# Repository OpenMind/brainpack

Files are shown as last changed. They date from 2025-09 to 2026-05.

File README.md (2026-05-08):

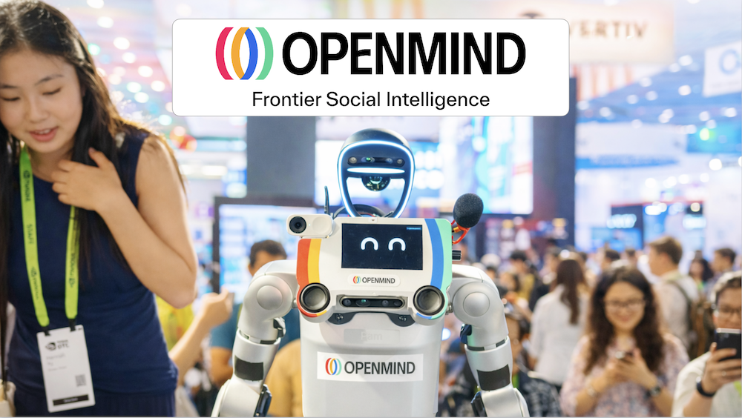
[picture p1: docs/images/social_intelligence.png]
OpenMind Scoial Intelligence


# BrainPack for Unitree G1, Unitree Go2, and LimX Tron 1

## Introduction

The **BrainPack** provides an easy to use, modular compute and development platform for robotics, integrated with the Unitree G1, Unitree Go2, and LimX Tron 1 (and other robots, coming soon). 

Included in the design are sensors and outputs that allow your robot to understand and react to its environment and interact with humans. The BrainPack with [Nvidia Thor](https://developer.nvidia.com/blog/introducing-nvidia-jetson-thor-the-ultimate-platform-for-physical-ai/) can connect to OpenMind cloud endpoints for voice, spatial navigation, emotion generation, teleops, and other robot functionality. 

The purpose of the BrainPack is to empower rapid iteration and experimentation. It enables developers to explore vertical-specific solutions quickly, re-configuring the system efficiently to meet evolving research or customer needs.

## Cross-Platform - It's Wooftacular!

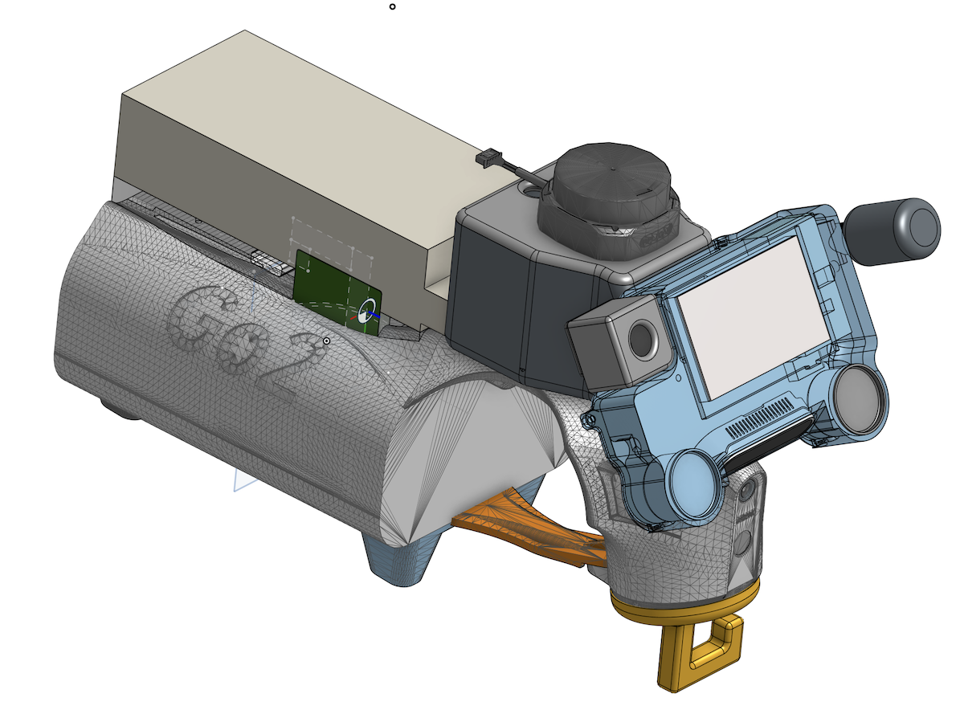
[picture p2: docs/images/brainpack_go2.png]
BrainPack OverView


## The Challenges in Robotics Development and Deployment

Currently, many robotics platforms are limited to academic research, single industrial problems, or for use as toys. When organizations attempt to deploy these robots into more complex and more realistic environments, significant limitations quickly become apparent.

### Hardware Limitations 

Common pain points include weak loudspeakers, lack of USB ports for additional sensors, lack of a touchscreen, lack of directional microphones, and outdated secondary computing modules. This means that even when purchasing a sophisticated robot such as Unitree G1, to conduct basic experiments and product development substantial time and effort must be spent on specialized cabling, 3D-printed parts, and add-on sensors.

### Fragmentation and Scalability

The robotics landscape is massive and highly fragmented. With over 400 active companies developing diverse robotic platforms and form factors, one impediment is the lack of hardware standards for integrating or swapping key components — whether that involves sensors, computing power, or power distribution. Imagine if your desktop PC were composed entirely of custom parts and you could not assemble the computer from standardized parts to fit your unique needs.

This forces developers into a difficult cycle: when a solution is built, it cannot be easily deployed across different robot brands and physical forms. This inefficiency means development efforts are tied to single-brand and single form factors. The BrainPack provides a standardized interface, establishing a common layer of capability that allows software and intelligence to run across multiple robot hardware platforms.

### Data Security and Privacy

For real world use of robots, it is important that humans feel comfortable in their presence, and this suggests physical privacy switches on cameras and microphones, as are standard for consumer webcams for example. The BrainPack allows cameras and microphones to be physically unplugged, or replaced with models that have privacy switches. Another feature commonly missing from most robots are indicator lights showing when cameras and microphones are active. 

### Our Solution: The BrainPack

We developed the BrainPack to address these blocks. This modular system provides deployment flexibility by providing one architecture that makes it easy to integrate, adapt, and explore diverse use cases. 

## Features

- **Designed for OM1** - Optimized for running OM1.
- **Human in the Loop** - Teleops - control your robot remotely or request help from another human whenever you need (via portal.openmind.com).
- **Developer Friendly** - Modular design with multiple connections and ports for easy hardware integration.

## Documentation

- [Bill of Materials](./docs/Materials.md)
- [CAD Files](./CAD/)
- [Assembly Instructions](./docs/Assembly.md)

## Repository Structure

```
PRISM/
├── README.md
├── docs/
│   ├── Materials.md       # Bill of Materials
│   └── Assembly.md        # Assembly Instructions
├── CAD/
    └──                    # STL files for 3D printing
```

## NonCommercial Use License

The contents of this repository — including CAD models, STL files, technical drawings, bill of materials, and assembly instructions for the OpenMind BrainPack — are released by OpenMind, Inc. under the Creative Commons Attribution-NonCommercial 4.0 International License (CC BY-NC 4.0): https://creativecommons.org/licenses/by-nc/4.0/

You are free to download, study, modify, fabricate for personal use, and share these materials for non-commercial purposes — including personal, educational, and academic-research use — provided you give appropriate credit to OpenMind, Inc., link to the license, and indicate any changes you have made.

Any commercial use is expressly reserved and requires a separate written license from OpenMind, Inc. "Commercial use" includes, without limitation: manufacturing the design (or any derivative of it) for sale; incorporating the design into a product, service, or system offered for sale or used commercially; using the design in connection with paid services; and distributing the design as part of any commercial offering.

No trademark rights in "OpenMind" or "BrainPack" any associated marks are granted by this license. No patent rights are granted, whether express or implied. OpenMind, Inc. retains all rights not expressly granted herein.

For commercial licensing inquiries, please contact hello@openmind.com.

---

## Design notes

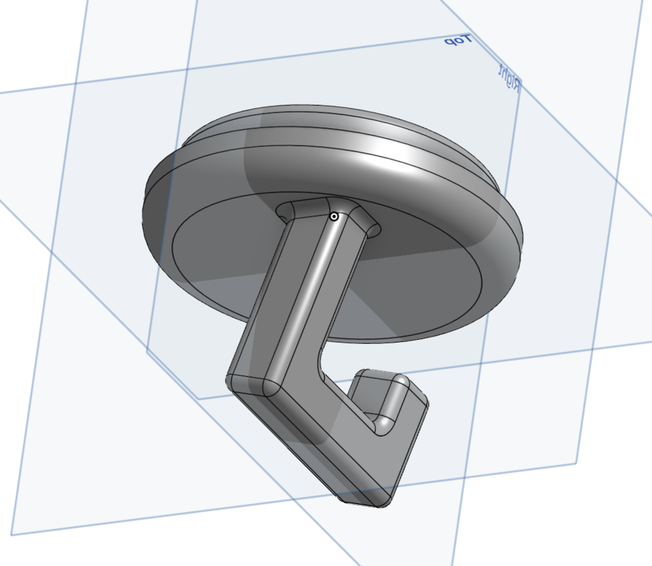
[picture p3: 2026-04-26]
docs/images/go2_mounth_hook.png

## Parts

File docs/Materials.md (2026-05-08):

<!-- TOC start (generated with https://github.com/derlin/bitdowntoc) -->
- [1. Safety](#safety)
   * [1.1 DANGER: Power Budget and Thermal Limits](#danger-power-budget-and-thermal-limits)
   * [1.2 DANGER: Robot Stability](#danger-robot-stability)
- [2. Materials](#materials)
   * [2.1 Display Unit ("Face")](#display-unit-face)
   * [2.2 Face and Sensor Carrier ("Head"); LiDAR](#face-mounting)
      + [2.2.1 Unitree G1](#unitree-g1)
      + [2.2.2 Unitree Go2 and LimX Tron 1](#unitree-go2-and-limx-tron-1)
   * [2.3 Thor Cradles](#thor-cradles)
      + [LimX Tron 1](#limx-tron-1)
      + [Unitree G1](#unitree-g1-1)
      + [Unitree Go2](#unitree-go2)
- [3. Cables and Power](#cables-and-power)
   * [3.1 Thor Power Harness](#thor-power-harness)
   * [3.2 Power Electronics](#power-electronics)
      + [LimX Tron 1 Power Cable](#limx-tron-1-power-cable)
      + [Unitree G1 Power Cable](#unitree-g1-power-cable)
      + [Unitree Go2 Power Cable](#unitree-go2-power-cable)
   * [3.3 Power Budget](#power-budget)
      + [Powered USB Hubs](#powered-usb-hubs)
      + [Example Power Calculation for Entire System](#power-budget-total)

<!-- TOC -->
# BrainPack Materials

> NOTE: Refer to the Bill of Materials with approximate build cost [here](https://docs.google.com/spreadsheets/d/1YjTzyw0XH3A2SuCKs4Oi_q3m2KCcntqwOuZ239gBQtQ).
> Prices can vary based on supplier, region, availability, and where generic items are purchased.

<!-- TOC -->
## 1. Safety

<!-- TOC -->
### 1.1 DANGER: Power Budget and Thermal Limits

**Without proper design and measurement, it can easily happen that you operate a robot above its design power budget, which is dangerous. For safe use, you must carefully consider the robot's intended use, average and peak power requirements, the robot's physical environment (e.g. external air temperature, exposure to direct sun), and the power/thermal interplay of simultaneous movement, sensing, and compute.** 

Unless you get this right, you may experience fast battery drain, intermittent faults and resets, electrical shorts and fires, overheating, poor sensor performance and many other possible problems. 

**Example 1**: when a robot tries to speak (at max volume) and walk at the same time, while also running multiple large policies, this could overload (and reset) the power system. The humanoid will then suddenly crash to the floor. Testing individual robot subsystems in isolation will not surface this problem, which only occurs when the robot wishes to move, think, and speak at the same time.

**Potential Solution**: Prepare a power budget based on actual measurements of average and peak power draws. An inline **USB Voltage Current Power Tester Multimeter** (such as the [FNB58USB Voltage/Current/Power tester/monitor](https://www.fnirsi.com/products/fnb58)) is useful to measure the actual power draw of your sensors and other electronics payload in their final configuration. If needed, change how you are powering your computers and sensors, such as by moving loads to other power buses, providing powered USB hubs, or adding external batteries (but see [below](#danger-robot-stability)).

**Example 2**: The robot performs flawlessly in an air conditioned lab, but falls over frequently when deployed in a hot sunny environment. In this case, different joints are probably overheating, switching the system to emergency damp mode, resulting in a fall and subsequent damage to the robot. 

**Potential Solution**: ensure that your software monitors the temperature and power draw of all joints. If your software detects operation near the thermal limits, warn human and robot bystanders and train your small-brain subsystem to then perform a safe sink-to-floor action with an audible alarm and flashing light. A better long term solution is for the robot to autonomously seek shade or an air conditioned room prior to overheating.

**Example 3**: The robot performs flawlessly when it is not moving, but when it is navigating in even a small space, you notice an overall degeneration of WiFi and an angular dependence of WiFi signal strength, resulting in erratic performance for teleops (which relies on good video and audio). Teleops fails when the robot is walking North (or some other specific direction) but works well then the robot turns around and sits down. 

**Explanation and Potential Solution**: The Nvidia Thor dev kit contains an internal Wi-Fi 6E module and its two antennas are located inside the dev kit, at the bottom of the "back" of the unit. If you mount the Thor on the back of the Unitree Go2, these two antennas will be close to the dog's power electronics and the two hip motors. In addition, depending on how the robot is pointing, the antennas at the lower back of the Thor can be occluded relative to the WiFi base station. We recommend adding an high-quality omnidirectional WiFi antenna to a high point of your robot and then connecting it to the AW-XB560NF via custom I-PEX MHF4 terminated coax. Rewiring the internals of the Nvidia Thor Dev kit is somewhat involved and exceeds the scope of this introductory write up. 

<!-- TOC -->
### 1.2 DANGER: Robot Stability

**CAUTION: adding extra mass (such as external computers, sensors, grippers, and batteries) to the robot will affect your motion policies and the robot's stability and ability to navigate terrain. You may for example observe the robot swaying back and forth while simply trying to stand. Solution: train custom motion policies for your robot in its final mass configuration.**

<!-- TOC -->
## 2. Materials

<!-- TOC -->
### 2.1 Display Unit ("Face")

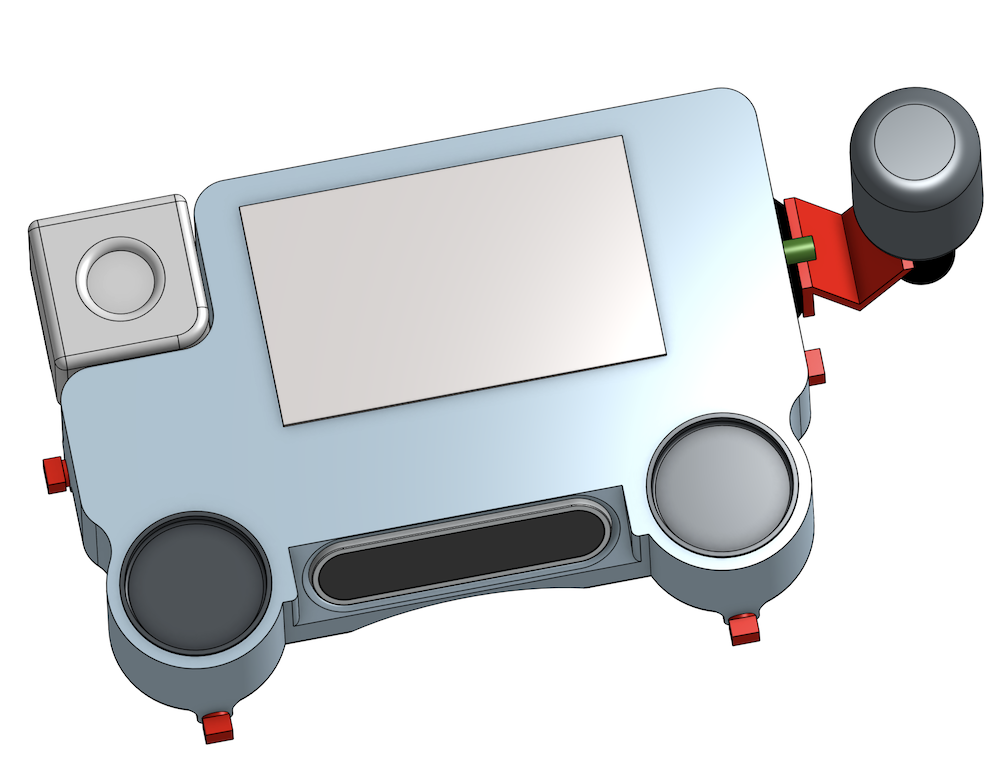
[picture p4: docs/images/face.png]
Front of Universal Face

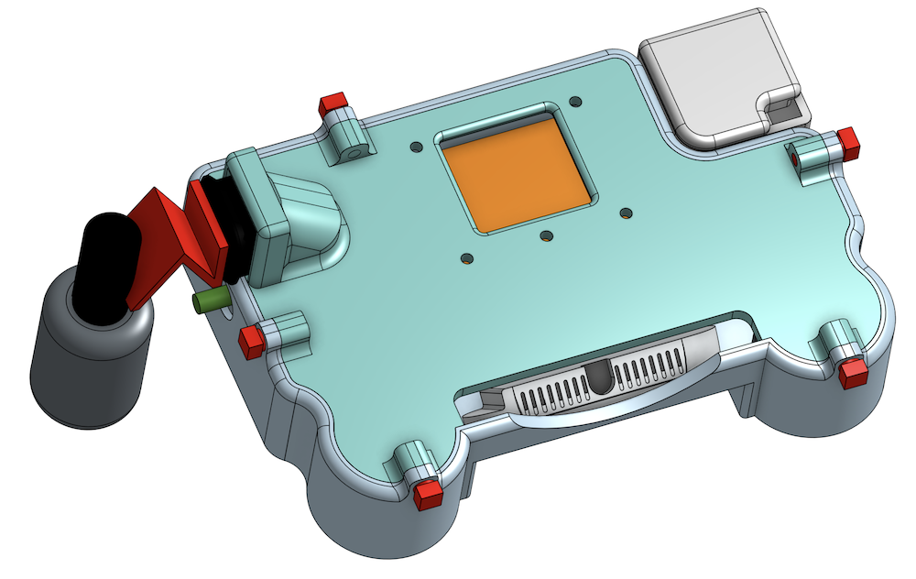
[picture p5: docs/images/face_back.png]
Back of Universal Face


| Name | Quantity |  Link | 
|---|---|---|
| Face Bezel | 1 | [stl](../CAD/Universal_Face/UniFace.stl) | 
| Face Back (Unitree Go2, LimX Tron 1) | 1 | [stl](../CAD/Universal_Face/FaceBack.stl) |
| Face Back (Unitree G1) | 1 | [stl](../CAD/Universal_Face/FaceBack_G1.stl) | 
| Widefield Camera Box | 1 | [stl](../CAD/ArduCam_FishEye/CameraEnclosure.stl) |
| Widefield Camera Box, Lid | 1 | [stl](../CAD/ArduCam_FishEye/CameraLid.stl) |

**<ins>1 ea. Flexible HDMI to HDMI Cable</ins>** This is used to connect the Thor to the LCD screen. Suggested part: Twozoh Flexible HDMI to HDMI Cable Right Angled 90° 1FT Ultra Thin and Slim HDMI Cord Support 3D/4K@60Hz
- For Unitree G1 and Go2: 1FT length: https://www.amazon.com/dp/B09XHYH4KY
- For LimX Tron 1: 3.3FT length: https://www.amazon.com/dp/B09XHZD6Z2

**<ins>1 ea. Fisheye RGB Camera</ins>** Suggested part: Arducam 1080P Low Light WDR Ultra Wide Angle USB Camera Module 2MP CMOS IMX291 160 Degree Fisheye Mini UVC USB2.0 SKU: B0202 [Purchasing link](https://www.arducam.com/arducam-1080p-low-light-wdr-ultra-wide-angle-usb-camera-module-for-computer-2mp-cmos-imx291-160-degree-fisheye-mini-uvc-usb2-0-spy-webcam-boa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)

**<ins>1 ea. RealSense Depth Camera (D435i)</ins>** Intel RealSense Depth Camera D435i, Silver 1080p Video Capture Resolution (82635D435IDK5P) https://www.amazon.com/Intel-RealSense-Depth-Camera-D435i/dp/B07MWR2YJB

**<ins>2 ea. Powered USB Hub</ins>** 4 Port USB 3.2 Gen 1 Micro Powered Hub PCBA w/ VL817 Chipset & ESD Surge Protection (CG-817X4AX1C-PD-PCBA) https://www.coolgear.com/product/4-port-usb-3-2-gen-1-micro-powered-hub-pcba-w-esd-surge-protection. This hub accepts 7 to 14V via a 2.5mm barrel jack. 

**<ins>2 ea. Barrel Power Jack, Male</ins>** Generic part, many suppliers. Suggested part: SDTC Tech 3 Sets 5.5 x 2.5 MM 10A DC Power Jack Socket Threaded Female Mount Connector Adapter & 12V Male DC Power Pigtail Cable with Dustproof Plug https://www.amazon.com/dp/B0B6FFN4V5 

**<ins>1 ea. High-Brightness Touch Screen</ins>** Waveshare 5 inch High-Brightness Touch Screen, 1024x600 Pixels Toughened Glass Panel, HDMI Interface, IPS Panel SKU: 27960 Mfr. #: 5DP-CAPLCD-H https://www.waveshare.com/5dp-caplcd.htm?sku=27960

**<ins>1 ea. Audio Amplifier</ins>** DROK 15W+15W 2.0 2pcs 12V Amplifier Board, Dual Channel Audio Amplifier Board PAM8620 DC 8-26V Digital Stereo Amp Module Class D Mini Power https://www.amazon.com/dp/B0CQJRL235 **Design notes**: Working voltage: DC8~26V, 15W stereo (24V 8ohm)/ 10W stereo (12V 8 ohm), if connect 4 ohm or 2 ohm speaker, the power will be automatically limited to 15W. Calculation: We are powering with 12V. Assuming auto limiting to 15W per side, aka (12V/15W =) 1.25 A per channel, the combined max power draw is limited to 1.25 + 1.25 = 2.5A, with overhead that works out to ~3A. 

**<ins>2 ea. Speaker 42mm 8W 4ohm</ins>** Mouser #: 665-AS04204PR Mfr. #: AS04204PR Mfr.: PUI Audio https://mou.sr/4sO2Qsp. These are 4 ohm speakers. The DROK audio amplifier will auto limit power to 15W per side (which overloads the speakers, leading to distortion, so do not turn the volume up all the way). 

**<ins>1 ea. Audio Cable</ins>** Seadream 3.5mm Aux Cable Short 2Pack 8 inch 3Port 3.5mm Right Angle Male to Male Stereo Audio Cable https://www.amazon.com/dp/B01L0YPVOY

**<ins>1 ea. Sound Card ADC and DAC</ins>** SABRENT USB External Stereo Sound Adapter USB-A (do not buy USB-C version - degraded audio quality) https://www.amazon.com/dp/B00IRVQ0F8

**<ins>1 ea. Directional Microphone</ins>** Comica Camera Microphone, CVM-VM10II Directional Microphone Cardioid Shotgun Video Camcorder Microphone https://www.amazon.com/dp/B0748CYPDJ **Design notes**: retain included 3.5 mm TRS cable; will be used in final assembly

**<ins>1 ea. Microphone Mount</ins>** SMALLRIG Cold Shoe Mount Adapter with 1/4 Thread Hole – 1241 https://www.amazon.com/dp/B00HJFBUCQ

**<ins>5 ea. M3 Threaded Inserts for 3D Printing Components</ins>** Many suppliers, for example: Kadrick 520Pcs M2 M3 M4 M5 Threaded Inserts Assortment Kit for 3D Printing Components Metric Brass Knurled Nuts https://www.amazon.com/dp/B0D5V3TZLB

**<ins>5 ea. M3 x 8mm Thread Pitch Cap Screws</ins>** Many suppliers, for example: Iexcell 100 Pcs M3 x 8mm Thread Pitch 0.5 mm Stainless Steel 304 Hex Socket Button Head Cap Screws Bolts Kit https://www.amazon.com/dp/B08H2HTTRT

#### USB Cables

**<ins>1 ea. USB Cable for RealSense</ins>** Suggested part: SUNGUY USB C 3.1 Gen 2 USB A 0.3m (B104-0.3m). This cable is commonly sold as a 1FT cable; the total length of this cable (all inclusive) is actually 13 1/4 inches. This is a good length to run from the RealSense to the powered USB hub inside the head unit. https://www.amazon.com/dp/B0B28ZCV2Y

**<ins>1 ea. USB Cable for Touchscreen Data/Power</ins>** Suggested part: Aceyoon 90 Degree USB C Cable 0.6ft Short Right Angle Type C https://www.amazon.com/dp/B096VYVR17

**<ins>2 ea. USB Cable for Hub to Thor</ins>** Suggested part: SUNGUY USB C 3.1 Gen 2 USB A 0.15m. These cables are a good length to run from the powered USB hubs to the Nvidia Thor. https://www.amazon.com/dp/B0CTMSCQQW

**Design Notes**: The RPLidar S2 comes with two short USB-A cables, which can be used without modification. The SABRENT USB-A sound card does not need a cable. The Arducam comes with a USB-A cable but it is far too long so it needs to be replaced with a custom cable which is easy to fabricate manually.  

<!-- TOC -->
### 2.2 Face and Sensor Carrier ("Head"); LiDAR

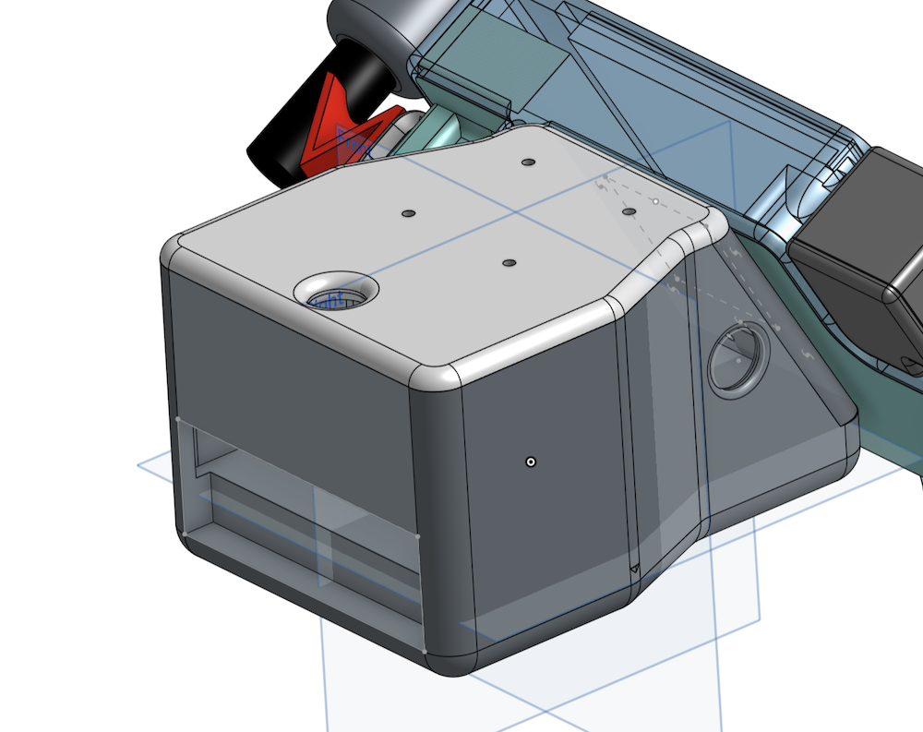
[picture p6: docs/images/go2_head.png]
Unitree Go2 Head

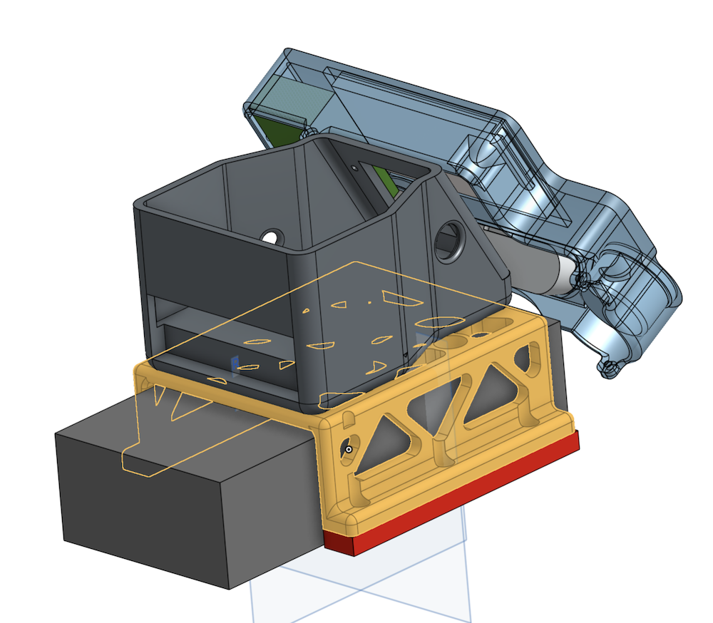
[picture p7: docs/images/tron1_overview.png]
Tron 1 Head Carrier


| Robot  | Name | Quantity | Link |
|---|---| --- |---|
| Unitree Go2, LimX Tron 1 | Face and Sensor Carrier ("Head") | 1 | [stl](../CAD/Universal_Face/Head.stl) |
| Unitree Go2, LimX Tron 1 | Face and Sensor Carrier, Lid | 1 | [stl](../CAD/Universal_Face/HeadLid.stl) |

<!-- TOC -->
#### 2.2.1 Unitree G1

To mount the face to the Unitree G1, you will need M6 cap screws and lock nuts.

**2 ea. M6 x 25mm Cap Screws** with nylon lock nut. Generic part, many suppliers.

The Unitree G1 is supplied with an internal [Livox Mid360](https://www.livoxtech.com/mid-360). Please refer to the Unitree and Livox documentation for information on the Mid360.  

<!-- TOC -->
#### 2.2.2 Unitree Go2 and LimX Tron 1

To mount the face to the **Face and Sensor Carrier ("Head")**, which is what mounts to the Unitree Go2 and the LimX Tron 1, you will need M3x16mm cap screws and M3 lock nuts.

**4 ea. M3 x 16mm Cap Screws** with nylon lock nuts and washers. Generic part, many suppliers. 

**1 ea. RPLidar S2 - ToF LiDAR** 360 Degree Laser Range Scanner, 2D, 30-meter range, sunlight resistant, 10Hz (600rpm), 32kHz sample rate (angular resolution is 0.1125°). https://www.slamtec.com/en/s2

Once all the electronics/wiring has been completed, close the head with the lid. The lid also serves as the base of the [RPLidar S2 - ToF LiDAR](https://www.slamtec.com/en/s2). The RPLidar is mounted to the lid with 4ea. M3 x 8mm cap screws - the same ones that are used to connect the face unit to the face back.

<!-- TOC -->
### 2.3 Thor Cradles

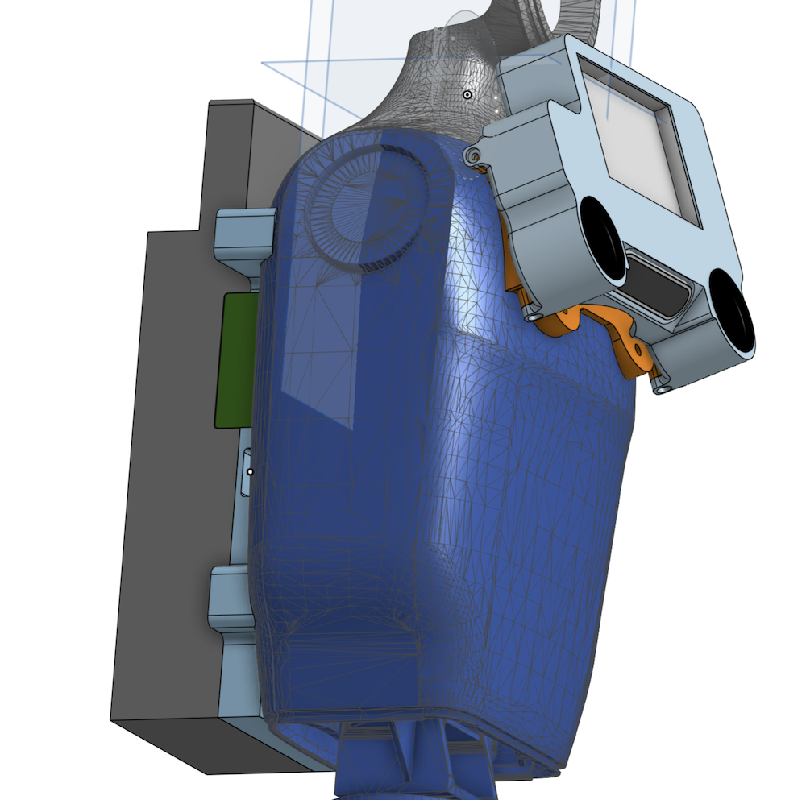
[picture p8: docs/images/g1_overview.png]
Side view of BrainPack for G1 with Thor and Thor cradle


| Robot | Name | Quantity | Link |
|---|---|---|---|
| Unitree G1  | Cradle with holdplates | 1 | [stl](../CAD/Unitree_G1) |
| Unitree Go2 | Cradle with holdplates | 1 | [stl](../CAD/Unitree_Go2) |
| LimX Tron 1 | Head Mount (Thor cradle equivalent) | 1 | [stl](../CAD/LimX_Tron1/HeadMount_withThorCutout.stl) |

<!-- TOC -->
#### LimX Tron 1

**1 ea. M5 T Slot Nut and Bolt Kit** Many suppliers, for example: 200Pcs 2020 Aluminum Extrusion M5 T Slot Nuts and Bolts Screws 20 Series Extruded Hardware Drop in T Nut Slide Nut M5x8 10mm for 20/20 80 20 2040 T V Slot Black Aluminum Profile Accessories https://www.amazon.com/dp/B08VGSNT2S

<!-- TOC -->
#### Unitree G1

**2 ea. Nylon Holding Strap** Fastening Hook and Loop Cable Straps, 10 Pack Black Self-Adhesive Cable Ties, Nylon Securing Straps with Buckles Adjustable and Reusable Cinch Straps for Cords Organized and Tidy(1" x 20") https://www.amazon.com/dp/B088FJCJDL

**2 ea. M6 x 35mm Cap Screws** Generic part, many suppliers. These are used to secure the TOP of the Thor cradle. 

**2 ea. M6 x 30mm Cap Screws** Generic part, many suppliers. These are used to secure the BOTTOM of the Thor cradle.

<!-- TOC -->
#### Unitree Go2

**1 ea. Nylon Holding Strap** Fastening Hook and Loop Cable Straps, 10 Pack Black Self-Adhesive Cable Ties, Nylon Securing Straps with Buckles Adjustable and Reusable Cinch Straps for Cords Organized and Tidy (1" x 20") https://www.amazon.com/dp/B088FJCJDL

**2 ea. M3 x 35mm Cap Screws** with washers. Generic part, many suppliers. These are used to secure the FRONT of the Thor cradle to the back of the dog.

**2 ea. M3 x 50mm Cap Screws** with washers. Generic part, many suppliers. These are used to secure the BACK of the Thor cradle to the back of the dog. 

<!-- TOC -->
## 3. Cables and Power

The Nvidia Thor is typically powered with:

* 4S 14.8V external LiPo (Unitree G1)
* 28 to 33.6V main robot power bus (Unitree Go2)
* 24V main robot power bus (LimX Tron 1)

The different robots have different power plugs:

* Unitree G1 - 24V/5A plug, XT30 connector - can be used for the audio amplifier directly (which accepts anything below 26V). You can use the XT30UPB-F 12V 12V/5A power output to power a USB hub. 
* Tron 1 - 24V, XT60 connector - can be used for the audio amplifier directly (which accepts anything below 26V) **AND** the Nvidia Thor. You will need a MATEKSYS BEC 12S to generate 12V to power the USB hubs.
* Unitree Go2 - 28 to 33.6V, XT30 connector - can be used for the Nvidia Thor **AND** via a step-down (buck) regulator, the audio amplifier and the powered USB hubs.

**NOTE: In general, you will need to design, fabricate, and assemble a custom step-down regulator which (1) takes 24 to 34V and (2) provides 12-17V for the audio amplifier and 5V 2A for the LCD screen back-lighting. In an emergency, you can use 2 ea. MATEKSYS BEC 12S Pro Synchronous switching step-down regulators, or equivalent, but this is probably not ideal.**

<!-- TOC -->
### 3.1 Thor Power Harness

Thor Power Cable, MICRO-FIT3.0 R-S 4 CIRCUIT 600MM<br>
DigiKey #: 900-2147561043-ND Mfr. #: 2147561043<br>
https://www.digikey.com/en/products/detail/molex/2147561043/12180337<br>

<!-- TOC -->
### 3.2 Power Electronics

| Robot  | Name |
|---|---|
| All | MICRO-FIT3.0 R-S Thor Power Cable |
| All | Mil-spec hookup wire, M22759/16-20 Mil-Spec Tefzel Hi-Temp Stranded Wire 20AWG Gauge, Black |
| All | Mil-spec hookup wire, M22759/16-20 Mil-Spec Tefzel Hi-Temp Stranded Wire 20AWG Gauge, Red |
| All | Crimp butt connectors, heat shrink, associated tooling |
| All | 2.5 mm Barrel Jack connectors |
| Unitree Go2 and G1 | Male XT30 connector with wire leads |
| Unitree Go2 | MATEKSYS BEC 12S Pro 9-55V to 5/8/12V-5A Synchronous switching step-down (buck) regulator | 
| Tron 1 | Male XT60 connector with wire leads |
| Unitree G1 | Male EC5 connector with 14AWG wire leads |
| Unitree G1 | 120S 14.8V 10000 mAh LiPo battery with female EC5 connector and LiPo charger |
| Unitree G1 | CAMWAY 5PCS 2 in 1 1-8s LiPo Battery Low Voltage Buzzer Alarm |

<!-- TOC -->
#### LimX Tron 1 Power Cable

The Tron 1 provides 24V through an XT60 jack. The Tron 1 does not need a power converter to power the audio amplifier or the Thor, but does need a MATEKSYS BEC 12S to provide 12V to the USB Hubs. Add a drop of solder to short the 12V config pins of the BEC 12S so that it provides 12V rather than the default 5.2V. Use crimp butt connectors to connect the male XT60 plug to the MICRO-FIT3.0 (for the Thor), the MATEKSYS BEC 12S, and the power input to the audio amplifier. **You will damage the audio amplifier, the Thor, the robot, or all three, if you get this wrong. Do not reverse the polarity!**  

<!-- TOC -->
#### Unitree G1 Power Cable

The Unitree G1 **does not** provide sufficient power for both the Thor and the audio amplifier. Therefore, an external LiPo battery is needed to power the Thor. The G1 just powers the audio amplifier (via the 24V/5A XT30) and the powered USB hub (via the G1's 12V/5A XT30).

1. Connect (using crimp butt connectors, cover with mil-spec glue coated heat shrink) a male XT30 connector to the audio amplifier cables (red, black) from the face unit. Plug the XT30 plug into the **MIDDLE** G1 power supply, which provides 24V/5A. **You will damage the audio amplifier, the G1, or both, if you get this wrong. Do not reverse the polarity!** 

2. Connect (using crimp butt connectors, cover with mil-spec glue coated heat shrink) a male XT30 connector to the barrel jack connector which will power the USB hub. Plug the XT30 plug into the **RIGHT** power port, which provides 12V/5A. **You will damage the hub, the G1, or both, if you get this wrong. Do not reverse the polarity!** 

3. Connect (using crimp butt connectors, cover with mil-spec glue coated heat shrink) a Male EC5 connector to the MICRO-FIT3.0 R-S Thor power connector. This connector has 4 wires, two of which will be used for ground, and two of which will be used for 14.8V. Consult the Thor technical documentation to determine the correct wiring. **You will damage the Thor if you get this wrong. Do not reverse the polarity! WARNING FIRE HAZARD: Do not short the 120S 14.8V 10000 mAh LiPo battery!**  

4. Use a second Velcro nylon strap to attach the LiPo battery to the Thor cradle. Connect the _Lipo Battery Low Voltage Buzzer Alarm_ to the balance port of the LiPo battery to avoid damaging the LiPo battery due to over-discharge. **WARNING BATTERY DAMAGE: Do not fully drain the LiPo battery. The Thor will try to drain the battery below 13.6V, which will damage it and prevent further charging. Recharge the battery when it has discharged to 13.6V.**

<!-- TOC -->
#### Unitree Go2 Power Cable

The Unitree Go2 provides 28 to 33.6V, which is too much for the audio amplifier and the powered USB hubs. Solution: use a MATEKSYS BEC 12S Pro Synchronous switching step-down (buck) regulator to provide 12V to the audio amplifier and USB hubs. 

1. Connect (using crimp butt connectors, cover with mil-spec glue coated heat shrink) a male XT30 connector to **BOTH** the MICRO-FIT3.0 (for the Thor) and the power input of the MATEKSYS BEC 12S power buck. Add a drop of solder to short the 12V config pins of the BEC 12S so that it provides 12V rather than the default 5.2V. Connect the outputs of the BEC 12S to the red/black wires from the audio amplifier in the face unit and the barrel jack connectors for the powered USB hubs. **You will damage the audio amplifier, the Thor, the robot, or all three, if you get this wrong. Do not reverse the polarity!** 

2. Plug the XT30 plug into the 33.6V Go2 power supply port, after convincing yourself that you did not reverse the polarity in your cabling.

**WARNING HIGH CURRENTS: Assuming you are operating the Thor at its "MAX" setting and using a full set of sensors, the payload could use as much as 300W. The current rating for the Go2 power ("Output power interface DC28.8V") is not publicly documented (if you know what it is, please let us know). However, we have been able to draw 8A.**   

<!-- TOC -->
### 3.3 Power Budget

We recommend a [FNB58USB Voltage/Current/Power tester/monitor](https://www.fnirsi.com/products/fnb58) to measure actual power draw.

**USB Bus A** This must be externally powered<br>
USB-A Power for RPLidar S2 Laserscan - Operating Current: 40mA (sleep); 400mA (working, official datasheet); 340mA (working, measurement)<br>
USB-A Data for RPLidar S2 Laserscan - Operating Current: 40 mA (working, measurement)<br>
USB-A Microphone and Speaker ADC and DAQ - time sensitive data - Microphone only with Comica actual current 24 mA<br>
USB-A LCD Display power - Operating Current: 130mA (in sleep); 900mA (full power back-lighting)<br>

**USB Bus B** This should be externally powered<br>
USB-C RealSense - USB 3.1 critical - Operating Current: 60mA (sleep); 130mA (working, RGB only); 700 mA (working, peak, per datasheet)<br>
USB-A Arducam - normal video data rates, USB 2.0 ok - Operating Current: 210mA (working, measurement)<br>

<!-- TOC -->
#### Powered USB Hubs

For reliable and stable performance **you must use powered USB hubs**. We recommend **<ins>4 Port USB 3.2 Gen 1 Micro Powered Hub PCBA w/ VL817 Chipset & ESD Surge Protection (CG-817X4AX1C-PD-PCBA)</ins>** https://www.coolgear.com/product/4-port-usb-3-2-gen-1-micro-powered-hub-pcba-w-esd-surge-protection. This hub accepts 7 to 14V via a barrel jack connector: DC Barrel 2.5mm ID × 5.5mm OD, Center Pin Positive. This hub can provide 20W total power or 900 mA per port. You can obtain 12V from a MATEKSYS BEC 12S (or equivalent). The MATEKSYS BEC 12S can provide 5A (continuous) and 9A (peak) output. 

<!-- TOC -->
#### Example Power Calculation for Entire System

**Audio** Assume you are powering the audio amplifier with 12V and have connected 2 8W speakers. Assuming auto limiting to 15W per side, aka (12V/15W =) 1.25 A per channel, the combined max power draw is limited to 1.25 + 1.25 = 2.5A, with overhead that works out to 3A. 

**Powered USB Hub 1** 1.2 amp draw

**Powered USB Hub 2** 0.9 amp draw

Assuming you are powering the USB hubs with 12V, then assume 2.1A total draw. With the 12V audio system, that gives 2.1 + 3 = 5.1A worst case draw, which (just barely) can be handled by one BEC 12 (which is rated for 5A continuous and 9A peak). 

<!-- TOC -->
## 4. Reliable Networking

The Nvidia Thor dev kit contains a Wi-Fi 6E module (AzureWave AW-XB560NF IEEE 802.11ax (Wi-Fi 6/6E) and Bluetooth 5.3/5.4 combo module). The two antennas are located inside the dev kit. The antennas can be occluded depending on how the dev kit is mounted on your robot and how your robot is moving and angled relative to the WiFi base station. We recommend adding an omnidirectional WiFi antenna to your robot, and then connecting it to the AW-XB560NF via custom I-PEX MHF4 terminated coax. Rewiring the internals of the Nvidia Thor Dev kit is somewhat involved and exceeds the scope of this introductory write up.

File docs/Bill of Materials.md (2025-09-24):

# Bill of Materials
**v 0.2**

## Backpack Unit

| Name | Part Number | Quantity | Category | Fab | Build Notes | Link | Picture |
|---|---|---|---|-----|---|---|---|
| Shell | | 1 | Housing | 3D printed | | <STL file goes here> | |
| Base Mount bracket | | 1 | Housing | 3D printed | | <STL file goes here> | |
| Lid | | 1 | Housing | 3D printed | | <STL file goes here> | |
| AGX push fit bracket | | 1 | Housing | 3D printed | | <STL file goes here> | |
| Magnets for snap on lid | | 4 | Housing | 3rd party | | | |
| Openmind Powerboard | | 2 | Electronics | Custom Fab | Openmind PCB | | |
| Nvidia Jetson AGX Orin Developer Kit | ‎945-13730-0050-000 | 1 | Electronics | 3rd party | | https://www.amazon.com/NVIDIA-Jetson-Orin-64GB-Developer/dp/B0BYGB3WV4/ref=sr_1_2?s=electronics | |
| Waveshare Audio codec driver | ‎RS232/485 USB All | 1 | Electronics | 3rd party | USB drive enclosure is removed and discarded. | https://www.amazon.com/Waveshare-USB-Converter-Raspberry-Driver-Free/dp/B08R38TXXL | |
| Speakers | a19090500ux0199 | 2 | Electronics | 3rd party | +ve/-ve leads soldered to JST 4 pin adapter | https://www.amazon.com/uxcell-Internal-Magnet-Speaker-Loudspeaker/dp/B082ZPP56D | |
| Speaker cable (custom) | | 1 | Cabling | Custom Fab | Modified from cable that is shipped with the Waveshare Audio speaker system | | |
| Ethernet bridge | SPM10236514602 | 1 | Electronics | 3rd party | Need to remove (and discard) enclosure | https://www.amazon.com/dp/B0D9BN22ZX | |
| USB C to JST power connector for the Ethernet board | | 1 | Cabling | Custom Fab | | | |
| 2.1 mm Male Barrel Jack power in cable | | 1 | Cabling | Custom Fab | | | |
| 2.1 mm Female Barrel Jack power out cable | | 1 | Cabling | Custom Fab | | | |
| Split power delivery cable | | 1 | Cabling | Custom Fab | | | |
| 25 mm M3 socket head screw with washer for front 2 holes of interface bracket | | 2 | Screws | 3rd party | The SHORT screw are used near the head of the dog | | |
| 35 mm M3 socket head screw with washer for back 2 holes of interface bracket | | 2 | Screws | 3rd party | The LONGer M3 bolts are used near the tail of the dog | | |

## Display Unit

| Name | Part Number | Quantity | Category | Fab | Build Notes | Link | Picture |
|---|---|---|---|-----|---|---|---|
| Display Bezel | | 1 | Housing | 3D printed | | <STL file goes here> | |
| Lidar Mount | | 1 | Housing | 3D printed | | <STL file goes here> | |

### Display

| Name | Part Number | Quantity | Category | Fab | Build Notes | Link | Picture |
|---|---|---|---|-----|---|---|---|
| Elecrow 800x400 Touchscreen Display | RC050 | 1 | Electronics | 3rd party | | https://www.amazon.com/ELECROW-Raspberry-Touchscreen-Monitor-HDMI-Compatible/dp/B07FDYXPT7 | |
| MicroUSB cable for display power | 200017-BLKx2 | 1 | Cabling | 3rd party | Cable from this pack also used for RPLidar connection | https://www.amazon.com/Cable-Matters-Combo-Pack-Right-Inches/dp/B00S8GU03A | |
| HDMI cable for display | HD-016-0.3M-L | 1 | Cabling | 3rd party | | 90 Deg connector, Twozoh Flexible HDMI to HDMI Cable Left Angled 90° 1FT, Ultra Thin and Slim HDMI Cord Support 3D/4K@60Hz. https://www.amazon.com/dp/B09XHZB9X5 | |
| HDMI to DP adapter | 5e40d1e3-7769-4fd2-8da5-d54d582f8e3b | 1 | Adapter | 3rd party | | Displayport to HDMI Adapter 4K 24K Gold Plated Displayport DP to HDMI Female Converter. https://www.amazon.com/dp/B09MTKHFKR | |

## Laserscan/LIDAR

| Name | Part Number | Quantity | Category | Fab | Build Notes | Link | Picture |
|---|---|---|---|-----|---|---|---|
| RPlidar 2d Lidar | RPLIDAR A1M8 | 1 | Electronics | 3rd party | Legs are unscrewed and then the unit is mounted on top of the lidar mount. | https://www.amazon.com/Slamtec-RPLIDAR-Scanning-Avoidance-Navigation/dp/B07TJW5SXF | |
| MicroUSB bridge connector for RPlidar | | 1 | Cabling | 3rd party | | https://www.amazon.com/Cable-Matters-Combo-Pack-Right-Inches/dp/B00S8GU03A | |

## Webcam/microphone

| Name | Part Number | Quantity | Category | Fab | Build Notes | Link | Picture |
|---|---|---|---|-----|---|---|---|
| Logitech Brio Webcam | 960-001589 | 1 | Electronics | 3rd party | Webcam is glued into bezel, and the USB cable is shortened via a USB-A connector. | https://www.amazon.com/Logitech-Webcam-Meetings-Streaming-Built/dp/B0BXGFFSL1 | |
| Webcam USB-A jack | | | Cabling | Custom Fab | USB end for the shortened webcam cable to be plugged into the USB A port on the hub. | Maxmoral 10PCS USB 2.0 Connector A Type Male 4-Pin Plug with Black Plastic Cover DIY Connector. https://www.amazon.com/dp/B081YV9VDH | |

## USB HUB

| Name | Part Number | Quantity | Category | Fab | Build Notes | Link | Picture |
|---|---|---|---|-----|---|---|---|
| Coolgear powered USB Hub | CG-U3MINI4PH | 1 | Electronics | 3rd party | Enclosure is removed and discarded. | https://www.amazon.com/Coolgear-Powered-Port-Surge-Protection/dp/B07G7GP15C/ref=sr_1_4?s=electronics | |
| USB C to USB B 3.0 Cable | 201007-BLK-0.3m | 1 | Cabling | 3rd party | This must be a USB 3.0 cable otherwise the system does not work | https://www.amazon.com/Cable-Matters-Short-USB-3-0/dp/B0DN4NWJ9D | |
| Powered USB hub power cable (Barrel Jack to JST) | | 1 | Cabling | Custom Fab | Uses the barrel jack from the coolgear kit, butt connectors, and JST cables/plug | | |

## Depth Camera

| Name | Part Number | Quantity | Category | Fab | Build Notes | Link | Picture |
|---|---|---|---|-----|---|---|---|
| Intel D435i depth camera | 82635D435IDK5P | 1 | electronics | 3rd party | Uses cable that comes with the Unitree. Also uses a USB-C to USB-A adapter | | |
| Unitree 435 mount and cable | | 1 | mount/cable | 3rd party | Comes with each Go2 EDU, but we pay extra for it | | |
| USB-C to USB-A adapter | US701 | 1 | connector | 3rd party | For connecting the d435i to the Jetson AGX | https://www.amazon.com/UGREEN-Adapter-10Gbps-Converter-Samsung/dp/B0CY1Y3TSQ/ref=sr_1_4?s=electronics | |

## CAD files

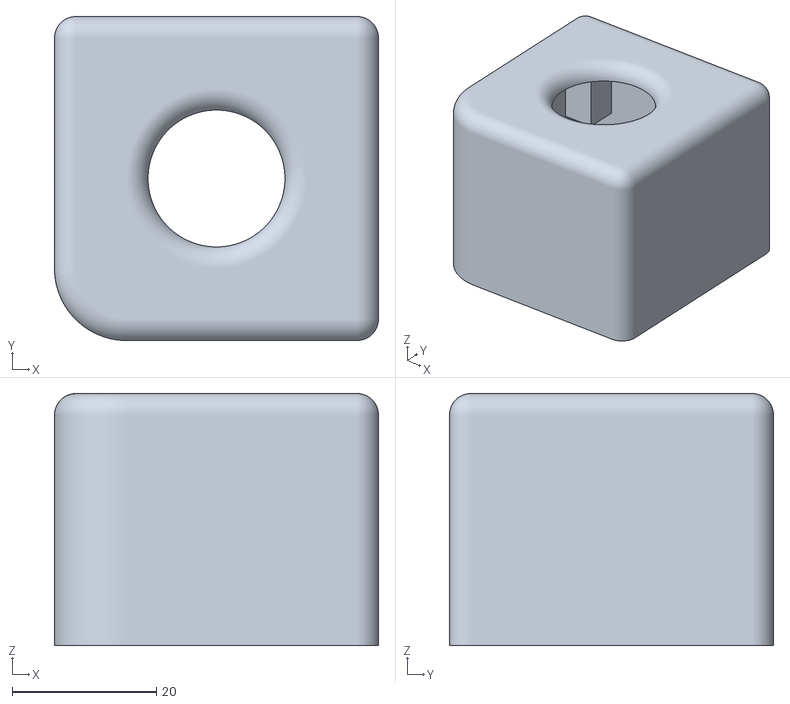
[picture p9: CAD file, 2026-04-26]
CAD/ArduCam_FishEye/CameraEnclosure.stl
45.0 x 45.0 x 35.0

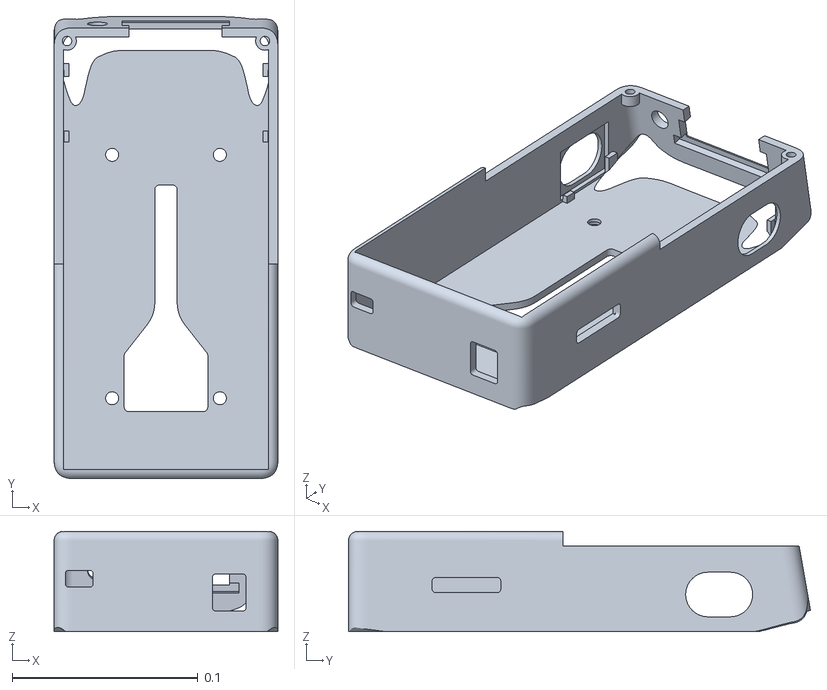
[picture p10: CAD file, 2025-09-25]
CAD/ComputerMountAGX - Box2.stl
0.12 x 0.249 x 0.054

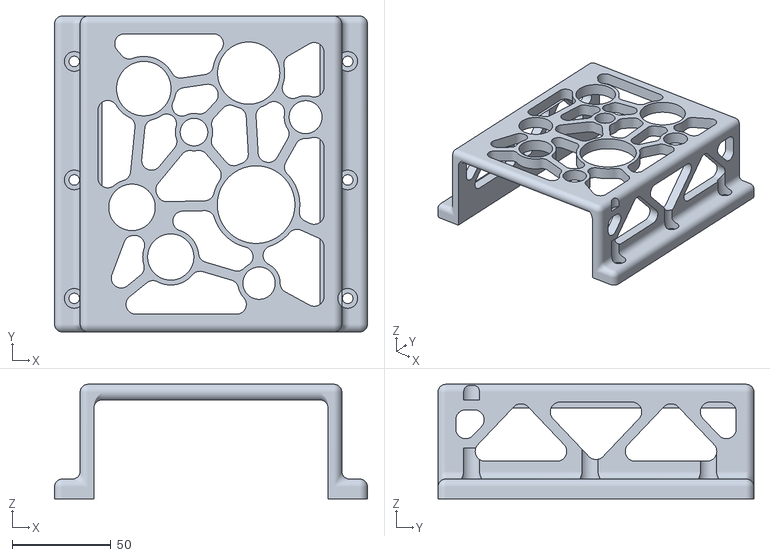
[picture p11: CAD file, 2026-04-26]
CAD/LimX_Tron1/HeadMount_withThorCutout.stl
158.5 x 160.0 x 58.0

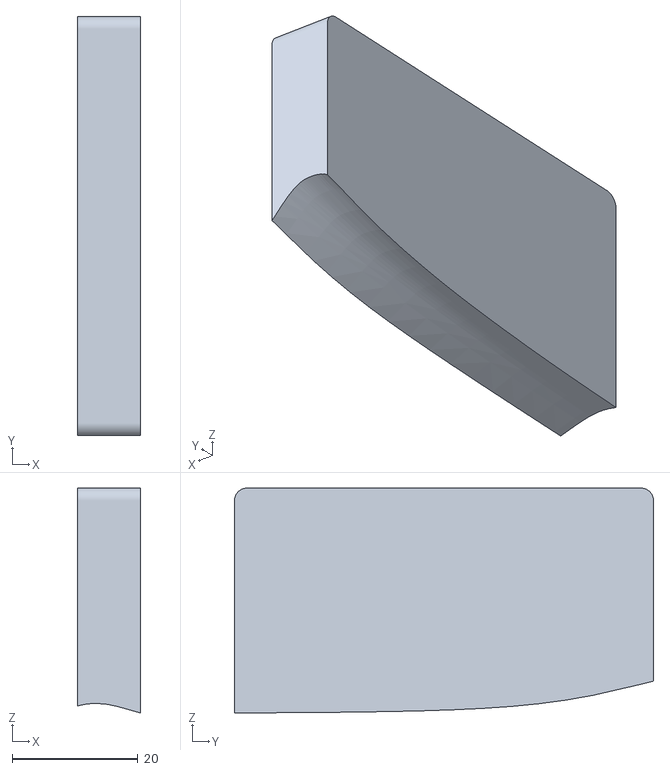
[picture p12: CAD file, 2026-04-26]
CAD/Unitree_Go2/ThorHoldPlate_Right.stl
10.0 x 66.6 x 35.7

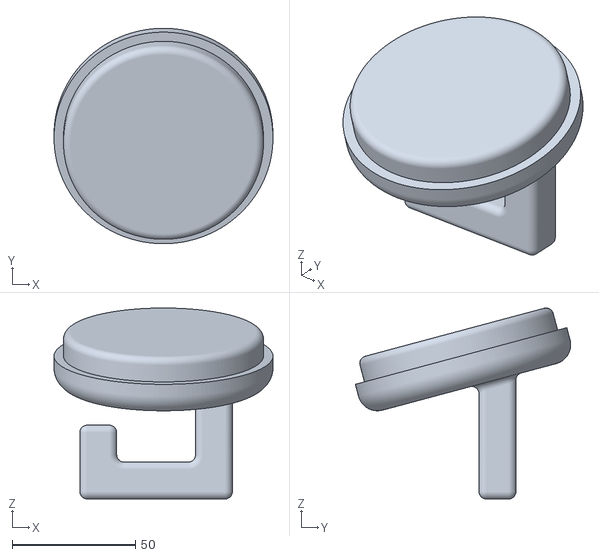
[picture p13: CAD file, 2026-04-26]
CAD/UniTree_Go2_Mouth/WoofHook.stl
89.0 x 87.5 x 77.6

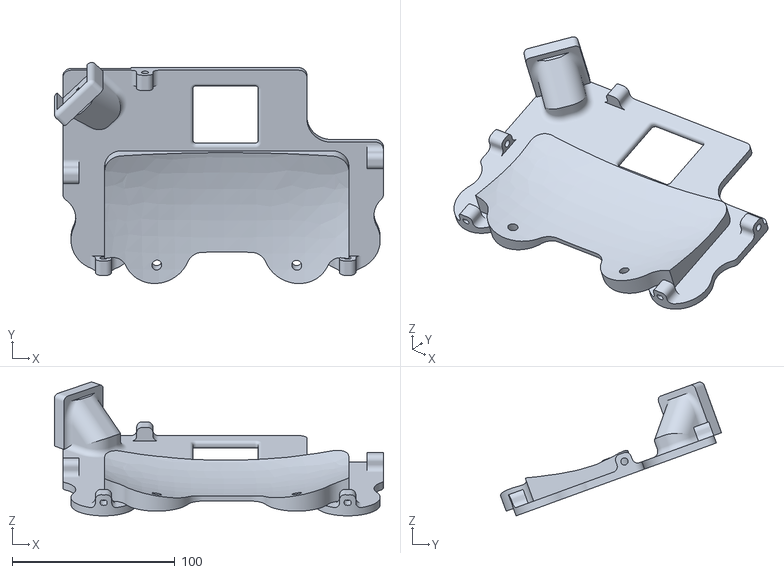
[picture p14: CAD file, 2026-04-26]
CAD/Universal_Face/FaceBack_G1.stl
202.1 x 135.9 x 82.2

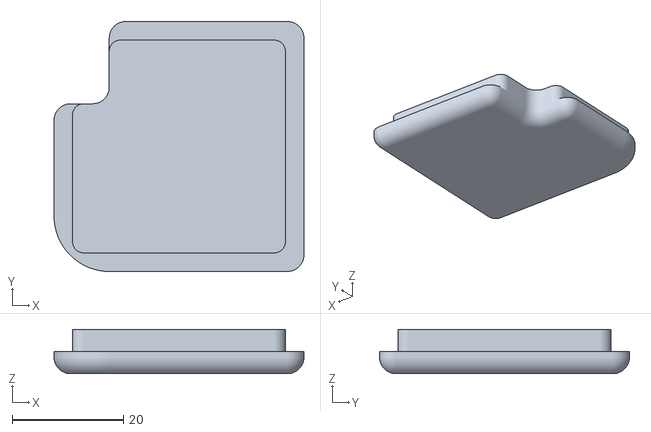
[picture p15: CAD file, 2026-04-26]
CAD/ArduCam_FishEye/CameraLid.stl
45.0 x 45.0 x 8.00

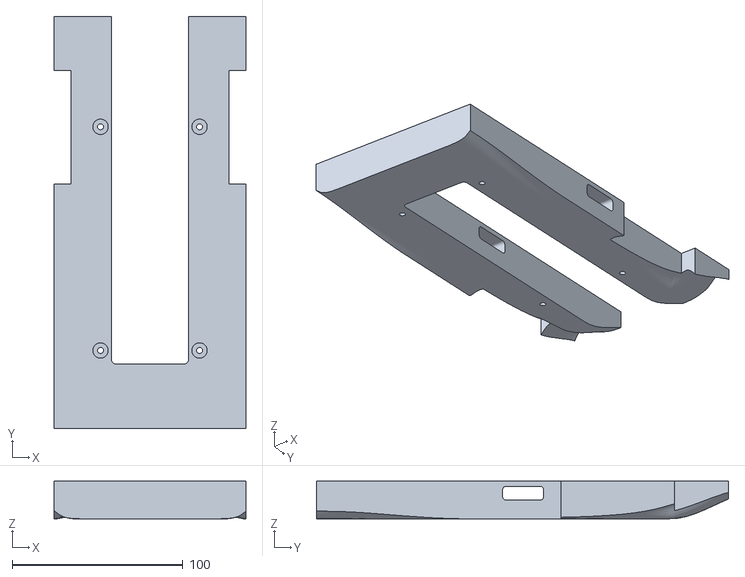
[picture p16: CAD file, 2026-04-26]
CAD/Unitree_Go2/ThorCradle.stl
112.4 x 241.3 x 22.0

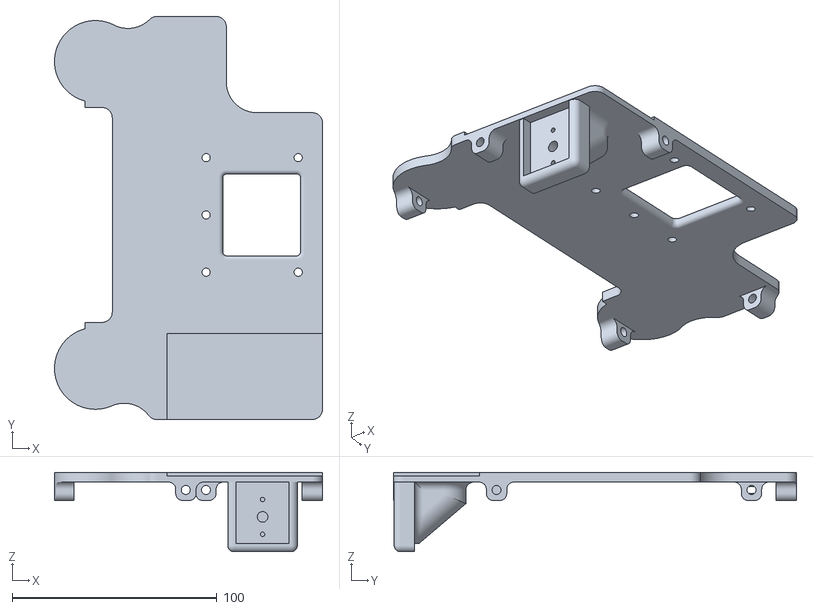
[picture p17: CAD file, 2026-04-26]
CAD/Universal_Face/FaceBack.stl
131.0 x 197.0 x 38.8

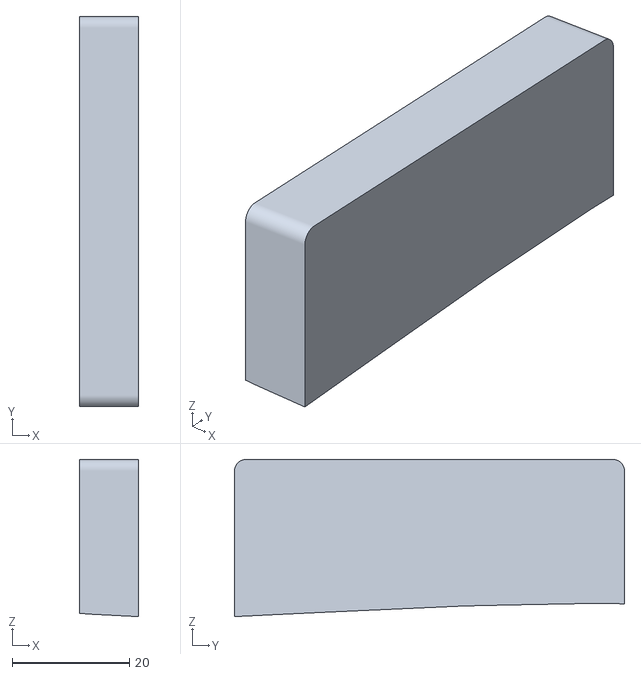
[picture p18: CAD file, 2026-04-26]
CAD/Unitree_G1/ThorHolkPlate_Right.stl
10.0 x 66.6 x 26.9

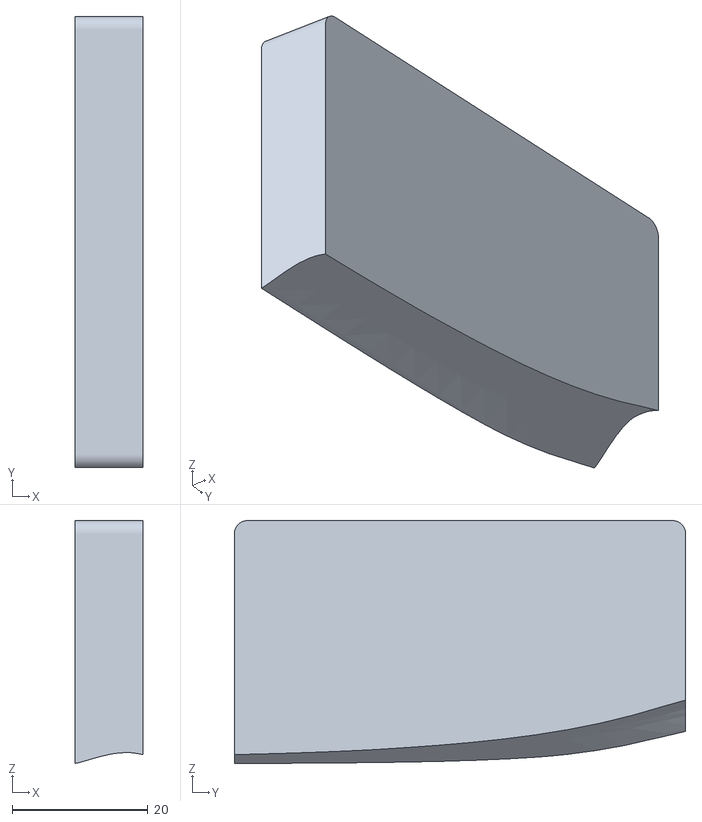
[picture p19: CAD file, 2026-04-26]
CAD/Unitree_Go2/ThorHoldPlate_Left.stl
10.0 x 66.6 x 35.8

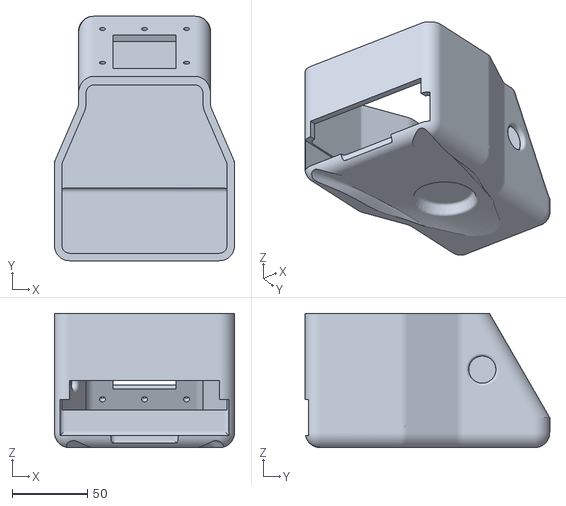
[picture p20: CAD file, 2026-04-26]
CAD/Universal_Face/Head.stl
120.0 x 163.0 x 89.5

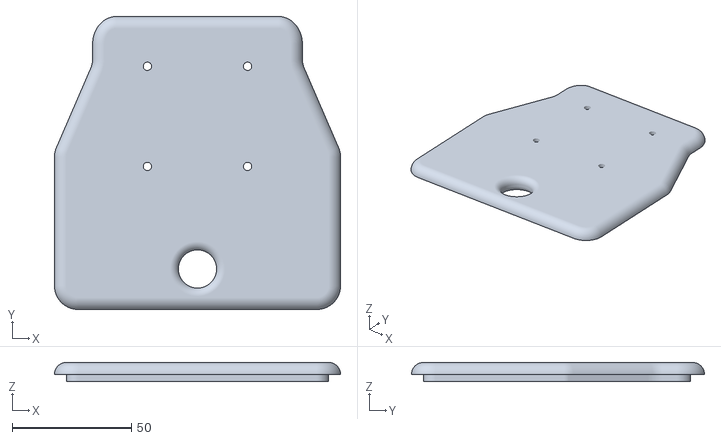
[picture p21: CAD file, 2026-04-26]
CAD/Universal_Face/HeadLid.stl
120.0 x 122.9 x 8.00

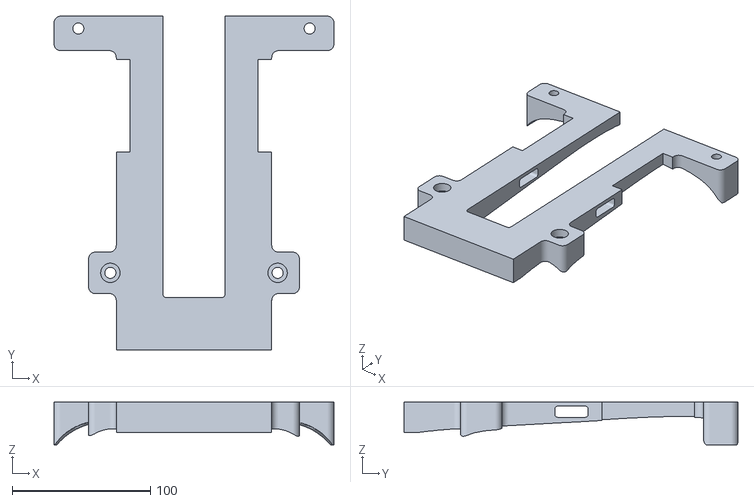
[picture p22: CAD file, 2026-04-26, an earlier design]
CAD/Unitree_G1/ThorCradle.stl
202.4 x 241.3 x 31.0

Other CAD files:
CAD/Unitree_G1/ThorHoldPlate_Left.stl

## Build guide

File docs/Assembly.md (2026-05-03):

<!-- TOC start (generated with https://github.com/derlin/bitdowntoc) -->
- [BrainPack Build Guide](#brainpack-build-guide)
   * [1. Introduction](#1-introduction)
   * [2. Prerequisites](#2-prerequisites)
   * [3. Assembly](#3-assembly)
      + [3.1. Face Unit](#31-face-unit)
      + [3.2. Face Back](#32-face-back)
      + [3.3. Arducam Camera](#33-arducam-camera)
      + [3.4. Internal Cabling](#34-internal-cabling)
      + [3.5. Thor Cradle](#35-thor-cradle)
      + [3.6. Attaching the Head](#36-attaching-the-head)
<!-- TOC end -->

<!-- TOC -->
# BrainPack Build Guide

<!-- TOC -->
## 1. Introduction

The BrainPack is a module that can be attached to various robots (such as the Unitree G1 and Go2, as well as the LimX Tron 1). As long as your robot provides power and can interface with external computers, most typically via an Ethernet cable, then the BrainPack should work for your robot. The BrainPack expects developer access to the robot and therefore will not work with toy/entertainment versions of the above robots (such as the Unitree Go2 Air).  

The BrainPack is designed for Human-Robot interaction research and pilot testing. The BrainPack allows you to rapidly test new combinations of advanced compute, new types of sensors, and new types of outputs and actuators. 

**NOTE: The correct assembly of, and safe use of, this research tool requires a fully equipped electronics test and assembly space with all the needed tools and equipment, such as soldering irons, hot glue guns, PCB reflow, crimp tools, multimeters, lab power supplies, thermal imaging (to monitor thermals), and other generic electronics and robotics test and assembly infrastructure.**

**NOTE: this write up is a high-level summary of the central steps required to assemble and use the BrainPack. We assume advanced familiarity with robotics hardware, associated actuators, batteries, and sensors, 3D printing, and related capabilities. The overall assembly process involves more than 300 specific steps. We only provide the most important ones in this write up. Robotics engineers will be able to follow along with minimal difficulty. If you have any questions please reach out to our engineers.**

[Materials](../docs/Materials.md)

[CAD Drawings](../CAD/)

<!-- TOC -->
## 2. Prerequisites

1. A Unitree Go2 Edu (for example)

2. All the needed [Materials](../docs/Materials.md)

3. An electronics and robotics rapid prototyping and development lab

<!-- TOC -->
## 3. Assembly

Regardless of movement platform (Unitree G1, Unitree Go2, LimX Tron 1) the system consists of (1) an Nvidia Thor mounted to the robot via a 3D printed cradle, and (2) a face unit. The "face" combines a screen, microphone, speakers, and other electronics. Users may add additional sensors such as a wide field RGB camera (e.g. an Arducam) or a sunlight resistant laser scan unit. 

The face is the most difficult part to assemble. Once assembled, the face is either connected directly to the robot (such as for the Unitree G1) or it is connected to the "head", which also houses cables and provides support for additional sensors. 

<!-- TOC -->
### 3.1. Face Unit

The face unit is composed of two 3D printed parts (the face bezel and the face back) and a variety of printed circuit boards, sensors, speakers, and other electronics. The face unit is easy to open and close through M3 cap screws.

1. Start with the 3D printed face bezel. 

2. Take the LCD screen and plug a 90° USB cable into the "touch" USB-C connector. 

3. Attach the 90° angled HDMI cable to the LCD screen. Route the cable up and bend it sharply so it lies flat on the LCD PCB. 

4. Peel off the screen protection film. Use hot glue to secure the LCD display in the face bezel.

5. Connect the two cables coming from the LCD display (touch and HDMI) to a computer, so that the screen turns on. Use the LCD screen configuration buttons (on the right side of the screen) to navigate to the brightness menu and adjust the brightness to 100%. These buttons will soon be inaccessible. We generally leave the screen at maximum brightness. Unplug the LCD screen and place it into the face bezel. Use hot glue to secure the LCD screen to the face bezel.

6. Use hot glue to secure the two speakers into the face bezel. Make sure to choose a good angle for the plus and minus speaker hook up lugs. In general, the speaker hook up lugs should point towards the middle of the face bezel for subsequent good soldering access for the speaker hook up wires.

7. Use hot glue to secure the RealSense 435i camera into the face bezel. Connect the 3.1 USB-C to USB-A cable to the RealSense. Use a dab of hot glue to provide strain relief to the USB cable.

8. Use permanent double sided Gorilla mounting tape to secure the 12S buck converter to the right inside cavity of the face bezel. Short the 12V bridge pins on the 12S buck converter to set it to 12V output rather than the default 5.2V. Use mil spec Teflon coated hook up wire (40cm length) to create a power cable for the 12S buck converter input power, and solder the ends to the 12V input of the buck converter. 

9. Use large electronic snips to cut off the bulky RCA stereo output connectors from the audio amplifier PCB. Otherwise, the RCA connectors will conflict with the rest of the assembly. Make sure to remove any dangling or superfluous pieces of metal; you want a clean PCB.

10. Turn over the audio amplifier, remove the volume knob, nut, and washer, snap the PCB in place with the volume adjuster projecting through the side of the bezel, and then mechanically secure the PCB to the bezel with the volume knob nut and a washer. At this point you should be looking at the back of the PCB of the audio amplifier. Now, directly solder connections (1) from the 12V power IN of the audio amplifier to the 12V OUT of the buck converter, and (2) from the signal out of the audio amplifier (left GND and +, and right GND and +) to the two speakers. **CAUTION: ensure that wires are routed in the flattest possible manner and make sure that the wires are not shorted by protruding pins**. Use hot glue and fabric electrical tape to secure the wires; press the fabric electrical tape into the still soft hot glue to generate securely mounted wires that will resist vibrations and strain.

11. Connect the right-angled side of the stereo audio cable to the 3.5mm jack of the audio amplifier.

12. At this point, the face bezel will have five cables coming from it:

* the two power lines (red and black) going to the buck converter
* the 3.5 mm jack stereo input cable 
* the USB-A touch/power cable to the LCD screen 
* the HDMI cable
* the USB 3.1 cable going to the RealSense camera

<!-- TOC -->
### 3.2. Face Back

1. Take the 3D printed face back. 

2. Attach the SMALLRIG Cold Shoe Mount Adapter with the provided three screws. Two of these are very small and one of these is a larger 1/4 bolt. These screws will be hard to get started into the 3D printed material unless you use a hobby knife to slightly open/roughen the hole openings. 

2. Insert 5 ea. M3 threaded brass inserts into the face back with a soldering iron or a heated insert positioning tool.

3. Connect the Comica directional microphone to the face back via the SMALLRIG cold shoe. Connect the 3.5mm TRS cable to the directional microphone. The right-angled end of the TRS cable goes into the back of the microphone. The straight connector will subsequently be plugged into the DAC.

4. Use 4 ea. M3x20mm cap screws to secure the face back to the 3D printed head. Use washers and nylon lock nuts to ensure that the face back does not separate from the head. 

5. Thread all five cables from the face through the face back aperture into the head. Use 5 ea. M3x8mm cap screws to secure the face to the face back.

6. Thread the 3.5mm TRS cable (straight side) through the small microphone cable opening on the side of the head.

<!-- TOC -->
### 3.3. Arducam Camera

1. Connect the Arducam to a computer and confirm correct focus of lens. Manually adjust the focus of lens as needed to achieve a sharp image.

2. Use hot glue to secure the Arducam PCB into the 3D printed enclosure. Manually build a replacement USB cable to connect the Arducam to a USB-A hub. The cable that comes with the camera is typically far too long. Use hot glue to firmly connect the camera cable to the camera enclosure to provide strain relief.

3. Use permanent Gorilla double sided sticky tape to mount the Arducam to the top left of the face unit. If you would like to change the angle of the Arducam, 3D print a small wedge and insert that between the camera and the face unit. 

4. Finally thread the Arducam USB cable through the large hole on the side of the head.

<!-- TOC -->
### 3.4. Internal Cabling

1. At this point you have many wires going into the head. Generally, those will terminate in USB-A connectors or consist of simple hook up wire. Connect all USB connectors to appropriate powered USB hubs to optimize power delivery and data transmission rates. It appears difficult at first, but there is just enough space to correctly route all cables in the head. Once you have achieved good cable routing, close the head with the provided head lid, which also serves as the mount for the RPLIDAR S2. If you feel you do not have sufficient space inside the head manually fabricate more compact USB and power cables.

2. For powering the USB hubs use the barrel jacks and connect them to 12V power converters according to your personal preference.

3. For powering the 12S power converter inside the face, connect the two power cables to your custom power cabling according to your own preference. We generally recommend not to solder any connections, but to use butt crimp connections and mil spec heat shrink tubing with internal adhesive. Minimize the length of any cabling and maximize the AWG of the cable to achieve a mechanically robust and safe power harness.

4. This power harness should also provide power to the Nvidia Thor. Consult the Nvidia developer documentation to determine which wires of the four pin Thor power connector to connect to your custom power harness.

<!-- TOC -->
### 3.5. Thor Cradle

1. Remove the secondary compute module from the back of the Go2 EDU (if present). Remove the Unitree black and white power cable, which we recommend replacing in its entirety with a custom power cable with the correct length. However, retain the short Ethernet cable.

2. Use the two M3x35mm cap screws with washers to secure the FRONT of the 3D printed Thor cradle to the back of the Go2. Use the two M3x50mm cap screws with washers to secure the REAR of the Thor cradle to the back of the Go2.

3. Thread a nylon holding strap through the two provided apertures of the Thor cradle.

4. Snap the two side plates into the Thor cradle. Note these side plates are not identical, but there is a left side plate and right side plate. Inspect the curvature of the Go2's back and then snap in the side plate that fits conformally. These side plates can be used to more securely hold the Nvidia Thor. We sometimes leave them off when we need extra space between the head and the Thor to adjust or check cables, for example.  
5. We recommend removing the Unitree LiDAR underneath the dog's chin. This standard LiDAR is heavy, loud, and has a low frame rate. You can fill the resulting hole under the chin of the dog with a 3D printed adapter, for example a hook or a simple gripper that allows the dog to carry small objects, bones, and bags, helping to solve the last mile delivery problem (for example).

<!-- TOC -->
### 3.6. Attaching the Head

1. Use hot glue to attach the head to the front top of the dog. Do not drill into the Go2's head since this is where the Go2's internal WiFi antenna is located.

## 4. Other Robots

### 4.1. LimX Tron 1

The assembly of the BrainPack for the LimX Tron 1 is almost identical to the process for the Unitree Go2. The main exceptions consist of the power delivery system since the LimX provides 24V only. Change your power harness as needed/desired. Also, with the LimX Tron 1 the Thor compute unit is placed directly on top of the Tron 1 and a custom 3D printed adapter with M5 T-Slot nuts and bolts is used to support the head. 

### 4.1. Unitree G1

For the Unitree G1 a special face back is used to directly mount the face to the front of the G1. Remove the Velcro-secured G1 plastic chest plate and drill two holes through the plastic chest plate. Then secure the face to the chest plate with 2 M6 bolts with nylon lock nuts. You will need to remove small amounts of foam with a hobby knife from the G1's front plate backing foam to provide space for the nylon lock bolts. 

**Congratulations, you have finished your BrainPack assembly and installation!**

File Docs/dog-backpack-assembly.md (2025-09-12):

# PRISM Assembly Instructions

## Hardware Requirements

Please refer to this document for hardware specifications, parts requirements and guidelines on custom fabrication.

Additionally, you may refer to these links for additional required information:

- [Bill of Materials](./BOM.xlsx)
- [CAD Drawings](../cad/)

## Parts and Components

### Electronics

There are several off-the-shelf components and electronics that may be used. We strongly recommend using only the parts listed in the Bill of Materials.

#### List of Electronics and 3rd Party Hardware

| Name | Quantity | Notes | URL | Image |
|---|---|---|-----|---|
| Elecrow 5" Display | 1 | | | |
| SLAMTec RPLidar | 1 | | | |
| Logitech Brio 101 | 1 | | | |
| Coolgear USB Hub | 1 | | | |
| Gigabit Ethernet Hub | 1 | | | |
| Waveshare USB Driver | 1 | | | |
| UXCell 4 Ohm Speakers | 2 | | | |
| NVIDIA Jetson AGX | 1 | | | |

### Custom Fabrication

This project requires several 3D printed housing parts which can be found in the [CAD directory](../cad/), as well as custom cabling. Provided in this document are reference images for cabling connections as well as basic instructions on how to do so. 

**⚠️ Safety Notice:** Please exercise caution when fabricating wire connections and always remember to do a safety power check before plugging power electronics.

#### Required Tools

| Name | URL | Image |
|---|-----|---|
| Soldering Iron, Flux and Solder Wire | | |
| Glue / Glue Gun | | |
| Wire Strippers | | |
| Robust electrical cabling / wires | | |
| Butt connectors | | |
| Heat Shrink Tubing | | |
| Heat Gun | | |
| Allen Key Set | | |
| Phillips Head Screwdriver | | |
| Strong Double Sided Tape | | |
| Wrench | | |
| Multimeter | | |

#### 3D Printed Parts Required

| Name | Quantity | CAD Model Link | Image |
|---|---|---|---|
| Backpack Shell | 1 | | |
| Backpack Mount Bracket | 1 | | |
| Jetson AGX Push Fit Bracket | 1 | | |
| Backpack Lid | 1 | | |
| Display Bezel | 1 | | |
| Lidar Mount | 1 | | |

#### Custom Fabricated Cabling Required

| Part Name | Quantity | Notes | Image |
|---|---|---|---|
| USB C to JST Connector | 1 | Power for Ethernet Board | |
| 2.1 Barrel Jack Power In Cable | 1 | External Power delivery from Powerboard | |
| 2.1 Barrel Jack Power Out Cable | 1 | Powerboard to Jetson AGX | |
| Split Power Delivery Cable | 1 | Power from Go2's Battery to 2 Openmind Powerboard PCBs | |
| Waveshare Speaker Cable | 1 | Shortened and modified to connect to speakers and fit inside backpack | |
| 25mm M3 Socket head screws | 2 | For mounting the backpack on the front of the Go2 | |
| 30mm M3 Socket head screws | 2 | For mounting the backpack on the back of the Go2 | |
| Logitech Brio Webcam USB A Connector | 1 | Shortened the cable from the webcam and connected to USB A | |
| 2.1 Barrel Jack to JST Connector | 1 | Power for Coolgear USB Hub | |

## Assembly Instructions

### Part 1: Display Unit Assembly

1. Connect the HDMI and MicroUSB cables to the Elecrow 5" display (connected at the left side).

2. Snap the display inside the slot in the Bezel. You may use glue to secure it in place.

3. Place the Logitech webcam in the slot to the right such that the camera and microphone slot into the 2 holes. You may use glue to secure it in place.

4. Secure the Coolgear USB hub on the side of the Lidar Mount.

5. Unscrew the legs on the RPLidar, then place the RPLidar on the raised front edge of the Lidar Mount. You may use glue to secure it in place.

6. Snap in the Display Bezel to the Lidar Mount using the sized slot at the top edge of the bezel. Glue to secure.

7. Plug in the USB connections to the Coolgear USB hub. There should be 3 USB A connectors connected in the front, with the Type B cable and the Barrel Jack Power In connected at the back.

### Part 2: Backpack Electronics Assembly

1. Shorten and prepare the Speakers (by soldering to the JST connector) then snap them into the Speaker groove in the Backpack shell.
   - Uxcell speakers
   - JST connector speaker wire (from waveshare audio driver)

2. Connect the JST connectors to the Waveshare USB driver.

3. Remove the Ethernet hub from its enclosure, then slot it into the front slot of the Backpack Shell. You may use Glue to secure it in place.

4. **(Recommended)** Route the speaker wires so that they are placed behind and under the Ethernet hub to minimize cable congestion.

5. Prepare the power delivery wires:
   - Split Power cable
   - 2.1 mm Barrel Jack Power In
   - 2.1 mm Barrel Jack Power Out

6. Place the 2.1 mm Female Barrel in the circular slot, then use the wrench to turn and thread it into the Backpack shell.

7. Connect all power cabling into the Powerboard (x2) using the screw terminals. Remember to verify polarity.

8. **(Recommended)** Use a multimeter to verify connections before usage.

### Part 3: Final Assembly

1. Remove the Standard compute unit that comes included with the Unitree Go2 Edu

2. Connect the Back Mount Bracket to the base of the Backpack Shell so that the two snap together.

3. Place the Mount Bracket on the back of the Unitree Go2 Edu, aligning the 4 screw slots on the shell with those on the Unitree Go2 Edu.

4. Use 25 mm M3 Sockethead screws to screw in the **front** 2 screws.

5. Use 30 mm M3 Sockethead screws to screw in the **back** 2 screws.

6. Place the AGX Push Fit Bracket into the back of the backpack shell, taking care not to damage the electronics or cabling.

7. Place the NVIDIA Jetson AGX on top of the 4 pins on the AGX Push Fit Bracket. Push from the top to secure it in place.

8. Connect the Split Power Cable to the Go2 Power Out, and the RJ45 Cable to the Ethernet board.

9. Connect the peripherals to the Jetson:
   - Waveshare audio driver
   - USB C to A Adapter and the Intel d435i
   - USB C Data cable from the Display Unit
   - HDMI to DP Adapter and the HDMI Cable from the Display unit

10. Plug in the 2.1 mm Power Barrel Jack to the Jetson Power In.

11. Snap on the lid, making sure that all cables are secured inside the backpack and none are left dangling outside.

12. Turn on the Unitree Go2.

## Safety and Testing

- Always verify power connections with a multimeter before first power-on
- Ensure all cables are properly secured and not pinched
- Double-check polarity on all power connections
- Perform initial power-on test with monitoring equipment ready

## Support

If you encounter any issues during assembly, please:
1. Check the [FAQ section](./FAQ.md)
2. Open an issue in this repository
3. Contact our support team

---

*Document Version: 1.0*

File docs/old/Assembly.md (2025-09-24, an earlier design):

# PRISM Build Guide

## Introduction: 

PRISM (Platform for Robotics Integration, Sensing and Modularity) is a complete hardware-software package that provides a generalized and universal hardware configuration to interface with proprietary robotics and expose it to widely used communication routines such as Robotics Operating System (ROS2), CYCLONEDDS, etc. 

Designed with the goal of Human-Robot interaction, PRISM aims to bridge the gap between robotics and software interaction and provide a platform for further development and research.

Included in this document is a detailed set of instructions to fabricate and assemble to a ready-to-develop state. 
Please refer below for hardware specifications, parts requirements and guidelines on 3D printing and custom fabrication.
Additionally, you may refer here for additional information:

[Bill of Materials](../docs/Bill_of_Materials.md)

[CAD Drawings](../CAD/)

[Cable Fabrication](#cable-fabrication-instructions)

[FAQ](../docs/FAQ.md)

## Quick Start Guide:

### Prerequisites:
See also  [List of Tools](#tools-overview)

    1. A Unitree Go2 Edu
    
    2. A complete PRISM kit
    
    3. Screwdriver and Allen Key Set

### Installation Steps:
    1. First, unplug the power and Ethernet cables that plug into the Unitree Go2 proprietary compute unit. 

    2. Remove the compute unit:
        i. Unscrew the 2 screws here (top), and here(back)
        ii. Remove the top lid, and unscrew the 4 screws attaching the lift handle.
        iii. Reattach the lid, and screw in the top and back screws.

    3. Attach the PRISM Base Mount Bracket to the bottom of the PRISM - Backpack. You may use adhesive.

    4. After lining up the screw slots on the PRISM - Backpack:
        i. Use the 25 mm Sockethead Screws to secure the top 2 slots.
        ii. Use the 30 mm Sockethead Screws to secure the bottom 2 slots.
    
    5. Place the AGX Push Fit Bracket into the back of the Backpack Shell, taking care not to disrupt the cabling. 
    
    6. Place the NVIDIA Jetson AGX on top of the bracket, aligning it with the raised pins on the bracket. Push from the top to secure it in place. 
    
    7. Attach the Front Unit to the raised circular mount near the head of the Unitree Go2. You may use adhesive to secure it in place.
    
    8. Connect the peripherals to the Jetson:
        i. Waveshare USB Audio Driver
        ii. RJ45 Ethernet Cable from the Ethernet Hub
        iii. USB C to A Adapter - Intel 435i Depth Camera
        iv. USB B Data Cable - Front Unit USB Hub
        v. HDMI to DP Adapter - HDMI cable for Front Screen
    
    9. Connect the USB C to JST Connector to the Powerboard to power the Front Unit.
    
    10. Connect the Split Power Cable to the Go2 Power Out, and the RJ45 to the Ethernet Board.
    
    11. Plug in the 2.1 mm Power Barrel Jack from the Powerboard into the Jetson AGX.
    
    12. Snap on the the lid, making sure that all cables are secured inside and none are left dangling.
    
    13. Turn on the Unitree Go2.

## Installation Prerequisites

### Parts Overview

| Name | Quantity | URL |
|:---:|:---:|:---:|
| Elecrow 5" Display | 1 | [Link](https://www.amazon.com/ELECROW-Raspberry-Touchscreen-Monitor-HDMI-Compatible/dp/B07FDYXPT7) |
| SLAMTec RPLidar | 1 | [Link](https://www.amazon.com/Slamtec-RPLIDAR-Scanning-Avoidance-Navigation/dp/B07TJW5SXF) |
| Logitech Brio 101 | 1 | [Link](https://www.amazon.com/Logitech-Webcam-Meetings-Streaming-Built/dp/B0BXGFFSL1) |
| Coolgear USB Hub | 1 | [Link](https://www.amazon.com/Coolgear-Powered-Port-Surge-Protection/dp/B07G7GP15C/) |
| Gigabit Ethernet Hub | 1 | [Link](https://www.amazon.com/dp/B0D9BN22Z) |
| Waveshare USB Driver | 1 | [Link](https://www.amazon.com/Waveshare-USB-Converter-Raspberry-Driver-Free/dp/B08R38TXXL) |
| UXCell 4 Ohm Speakers | 2 | [Link](https://www.amazon.com/uxcell-Internal-Magnet-Speaker-Loudspeaker/dp/B082ZPP56D) |
| NVIDIA Jetson AGX | 1 | [Link](https://www.amazon.com/NVIDIA-Jetson-Orin-64GB-Developer/dp/B0BYGB3WV4/) |
| 25mm M3 Socket head screws | 2 | [Link](https://www.amazon.com/Kadrick-Aassortment-4mm-40mm-Commonly-Stainless/dp/B0BPFXP2M9/) |
| 30mm M3 Socket head screws | 2 |  [Link](https://www.amazon.com/Kadrick-Aassortment-4mm-40mm-Commonly-Stainless/dp/B0BPFXP2M9/) |
| M3 Washers | 4 |  [Link](https://www.amazon.com/HELIFOUNER-Washers-Stainless-Diameter-Thickness/dp/B0B3RVM92N/) |
| USB C Male PCB Adapter | 2 | [Link](https://www.amazon.com/ANMBEST-Connector-Receptacle-Adapter-Support/dp/B091CRLJM2/) |
| USB A Make PCB Adapter | 2 | [Link](https://www.amazon.com/uxcell-Socket-Connector-Replacement-Adapter/dp/B07R2KNXTS/) |
| Male 4 pin JST Connector cable| 1 | Link |

### Tools Overview

The tools provided in the table below are some examples of tested equipment that is recommended for beginners. Experienced users should rely on their own discretion for tool selection. 

**⚠️ Safety Notice:** Please exercise caution when handling tools that involve high temperature or voltage.

| Name | URL |
|:---:|:-----:|
| Soldering Iron, Flux and Solder Wire | [Link](https://www.amazon.com/Gorilla-Heavy-Double-Sided-Mounting/dp/B082TQ3KB5/) |
| Glue / Glue Gun | [Link](https://www.amazon.com/Gorilla-8401509-Hot-Glue-Sticks/dp/B07K791YRP/)|
| Wire Strippers | [Link](https://www.amazon.com/haisstronica-Stripper-Automatic-Crimping-Universal/dp/B0B2NWK1QX/)|
| Robust electrical cabling / wires | Link |
| Butt connectors | [Link](https://www.amazon.com/Insulated-Connectors-Sopoby-Uninsulated-Electrical/dp/B0BZ8B3V6Q/)|
| Heat Shrink Tubing | [Link](https://www.amazon.com/Eventronic-Heat-Shrink-Tubing-Kit-3/dp/B0BVVMCY86/) |
| Heat Gun | [Link](https://www.amazon.com/ROMECH-400%C2%B0F-660%C2%B0F-Overload-Protection-Embossing/dp/B0CHVDL25P/) |
| Allen Key Set | [Link](https://www.amazon.com/ELEAD-Hex-Key-Allen-Wrench/dp/B0DJNF75BX/) |
| Screwdriver Set | [Link](https://www.amazon.com/uxcell-Socket-Connector-Replacement-Adapter/dp/B07R2KNXTS/) |
| Strong Double Sided Tape | [Link](https://www.amazon.com/Gorilla-Heavy-Double-Sided-Mounting/dp/B082TQ3KB5/) |
| Pliers | [Link](https://www.amazon.com/WORKPRO-7-piece-Pliers-Diagonal-Linesman/dp/B0105SSMRO/) |
| Multimeter |[Link](https://www.amazon.com/Klein-Tools-MM325-Multimeter-Manual-Ranging/dp/B0B57L9FNL/) |

### Custom Fabrication Guide

This project requires several 3D printed housing parts which can be found in the [CAD directory](../CAD/), as well as custom cabling. Provided in this document are reference images for cabling connections as well as basic instructions on how to do so. 

**⚠️ Safety Notice:** Please exercise caution when fabricating wire connections and always remember to do a safety power check before plugging power electronics.

| Part Name | Quantity | Notes |
|:---:|:---:|:---:|
| USB C to JST Connector | 1 | Power for Ethernet Board |
| 2.1 Barrel Jack Power In Cable | 1 | External Power delivery from Powerboard |
| 2.1 Barrel Jack Power Out Cable | 1 | Powerboard to Jetson AGX |
| Split Power Delivery Cable | 1 | Power from Go2's Battery to 2 Openmind Powerboard PCBs |
| Waveshare Speaker Cable | 1 | Shortened and modified to connect to speakers and fit inside backpack |
| Logitech Brio Webcam USB A Connector | 1 | Shortened the cable from the webcam and connected to USB A |
| 2.1 Barrel Jack to JST Connector | 1 | Power for Coolgear USB Hub |

### 3D Prints

We recommned using a standard **PETG-CF** reel. Carbon Fibre offers minimal interference with wireless connection circuits inside the enclosure.

| Name | Quantity | 3D Model  |
|:---:|:---:|:---:|
| Backpack Shell | 1 | [Link](../CAD/PRISM-Box.stl) |
| Backpack Mount Bracket | 1 | [Link](../CAD/PRISM-BaseMountBracket.stl) |
| Jetson AGX Push Fit Bracket | 1 | [Link](../CAD/PRISM-AGXPushFitBracket.stl) |
| Backpack Lid | 1 | [Link](../CAD/PRISM-BoxLid.stl) |
| Display Bezel | 1 | [Link](../CAD/PRISM-Bezel.stl) |
| Display Bezel Backplate | 1 | [Link](../CAD/PRISM-BezelBackplate.stl) |
| Front Housing | 1 | [Link](../CAD/PRISM-FrontHousing.stl) |

## Main Assembly
    
### Go2 EDU compute attachment removal

**The Unitree Go2 EDU includes an additional compute module mounted on its back. For the purposes of the this guide, we are going to remove it.** 

    1. Unplug the RJ45 cable and power cable coming from the Go2.

    2. Undo the 4 screws holding the module on the top.

    3. Undo the 2 screws holding the module on the bottom.

    4. Gently lift the module and its two mounting bars out of the way.

    5. Undo the 2 screws in the back lift handle connection

    6. Gently remove the top cover of the Go2.

    7. Undo the 2 handle screws at the front lift handle connection.

    8. Remove the lift handle and screw the top cover back on the Go2.

### Backpack

    1. Shorten and prepare the Speakers (by soldering to the JST connector) then snap them into the Speaker groove in the Backpack shell.
        - Uxcell speakers
        - JST connector speaker wire (from waveshare audio driver)

    2. Connect the JST connectors to the Waveshare USB driver.

    3. Remove the Ethernet hub from its enclosure, then slot it into the front slot of the Backpack Shell. You may use Glue to secure it in place.

    4. Recommended: Route the speaker wires so that they are placed behind and under the Ethernet hub to minimize cable congestion.

    5. Prepare the power delivery wires:
        - Split Power cable
        - 2.1 mm Barrel Jack Power In
        - 2.1 mm Barrel Jack Power Out

    6. Place the 2.1 mm Female Barrel in the circular slot, then use the wrench to turn and thread it into the Backpack shell.

    7. Connect all power cabling into the Powerboard (x2) using the screw terminals. Remember to verify polarity.

    8. Recommended: Use a multimeter to verify connections before usage.

### Display Unit

    1. Connect the HDMI and MicroUSB cables to the Elecrow 5" display (connected at the left side).

    2. Snap the display inside the slot in the Bezel. You may use glue to secure it in place.

    3. Place the Logitech webcam in the slot to the right such that the camera and microphone slot into the 2 holes. You may use glue to secure it in place.

    4. Secure the Coolgear USB hub on the side of the Lidar Mount.

    5. Unscrew the legs on the RPLidar, then place the RPLidar on the raised front edge of the Lidar Mount. You may use glue to secure it in place.

    6. Snap in the Display Bezel to the Lidar Mount using the sized slot at the top edge of the bezel. Glue to secure.

    7. Plug in the USB connections to the Coolgear USB hub. There should be 3 USB A connectors connected in the front, with the Type B cable and the Barrel Jack Power In connected at the back.

### Robot Mounting

    1. Attach the PRISM Base Mount Bracket to the bottom of the PRISM - Backpack. You may use adhesive.

    2. After lining up the screw slots on the PRISM - Backpack:
        i. Use the 25 mm Sockethead Screws to secure the top 2 slots.
        ii. Use the 30 mm Sockethead Screws to secure the bottom 2 slots.

    3. Place the AGX Push Fit Bracket into the back of the Backpack Shell, taking care not to disrupt the cabling. 

    4. Place the NVIDIA Jetson AGX on top of the bracket, aligning it with the raised pins on the bracket. Push from the top to secure it in place. 

    5. Attach the Front Unit to the raised circular mount near the head of the Unitree Go2. You may use adhesive to secure it in place.

    6. Connect the peripherals to the Jetson:
        i. Waveshare USB Audio Driver
        ii. RJ45 Ethernet Cable from the Ethernet Hub
        iii. USB C to A Adapter - Intel 435i Depth Camera
        iv. USB B Data Cable - Front Unit USB Hub
        v. HDMI to DP Adapter - HDMI cable for Front Screen

    7. Connect the USB C to JST Connector to the Powerboard to power the Front Unit.

    8. Connect the Split Power Cable to the Go2 Power Out, and the RJ45 to the Ethernet Board.

    9. Plug in the 2.1 mm Power Barrel Jack from the Powerboard into the Jetson AGX.

    10. Snap on the the lid, making sure that all cables are secured inside and none are left dangling.

## Testing and Verification

### Power On

    1. Before turning on the Unitree Go2, make sure that:
        i. The battery is correctly inserted into the robot. Listen for a click.
        ii. There is sufficient charge in the battery.
        iii. All power cables inside the PRISM enclosure are connected correctly and securely. 

    2. Turn on the Go2 by pressing the battery button. Use a short press then a long press.

    3. Once the robot is turned on, it will stand up on its own after a brief startup routine.

    4. Once the startup routine is finished, your Go2 will automatically boot and run OM1. 
    
**Congratulations, you have finished your PRISM setup!**

[//]: # (Troubleshooting)

## Appendix:

### Cable Fabrication Instructions

    1. USB C to JST Connector:
        1. Snap in JST cabling to the Pin Adapter
        2. (Optional) Check polarity on the USB C connector
        3. Using the soldering iron, solder the positive and negative leads of the JST cables to the USB C adapter. Remember to be careful not to apply too much solder and damage the connection.
        4. This USB C adapter will then be connected to the Ethernet Hub's USB C power.
        5. The JST pin adapter will be plugged into the OM1 powerboard. 

    2. 2.1mm Barrel Jack Power Cable (Male)
        1. Measure about 6 cm of cable length from the barrel jack, then cut the rest of the length.
        2. Using the wire strippers, strip out about 2mm of cable from each of the positive and negative ends.
        3. Using the soldering iron, gently tin the cable ends. Be careful not to add too much solder.
        4. Once tinned, screw positive and negative ends onto the screw terminals of the OM1 powerboard.

    3. 2.1mm Barrel Jack Power In Cable (Female)
        1. Measure about 6 cm of cable length from the female power adapter. 
        2. Using the wire strippers, strip out about 4mm of cable from each of the positive and negative ends.
        3. Using the soldering iron, gently tin the cable ends. Be careful not to add too much solder.
        4. Once tinned, screw positive and negative ends onto the screw terminals of the OM1 powerboard.
        5. Place the barrel into the front circular slot facing outwards. Make sure the cable ends are pointed inside the shell.
        6. Using pliers, rotate and thread the barrel into the front circular slot to secure it in place.

    4. Waveshare Speaker Cable
        1. Measure about 11 cm of cable length from the 4 pin JST connector. Each pair will be soldered to one speaker.
        2. Using the wire strippers, strip out about 4mm of cable from each of the positive and negative ends.
        3. Using the soldering iron, solder the positive and negative ends to their respectively marked terminals on the speaker. 
        4. Repeat this so that both speakers are soldered to the JST connector cable.

    5. Logitech Brio Cable
        1. Unbox and ready your Logitech Brio webcam.
        2. Remove the webcam from its housing unit. You should see a thin PCB with the attached camera and mic module.
        3. (Optional) For better cable management, you may shorten the USB cable. In this case, you must solder the power (red and black) and data lines (white and green) to a USB adapter so that it can be connected to the Coolgear USB Hub.

    6. 2.1 Barrel Jack (Male) to USB C Power
        1. Measure about 12 cm of cable length from the 2.1 barrel jack (male) connector.
        2. Using the wire strippers, strip out about 4 mm of cable from each of the positive and negative ends.
        3. (Optional) Verify the correct polarity for the USB C Connector.
        4. Using a soldering iron, solder the positive and negative ends to their respective terminals on the USB C Connector.

### Safety and Testing

- Always verify power connections with a multimeter before first power-on
- Ensure all cables are properly secured and not pinched
- Double-check polarity on all power connections
- Perform initial power-on test with monitoring equipment ready

## Support

If you encounter any issues during assembly, please:
1. Check the [FAQ section](./FAQ.md)
2. Open an issue in this repository
3. Contact our support team

---

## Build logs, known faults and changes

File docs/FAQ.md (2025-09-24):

# Frequently Asked Questions

## Overheating & Fire Risk

### Is there a risk of overheating if it runs for hours?
Running the backpack for hours over multiple charge cycles does not cause overheating.

### What safety cut-offs exist to prevent battery fires?
In case of high temperatures, the on-board computer (Jetson AGX) automatically shuts off to prevent damage to electronics. 

## Battery & Charging

### How long does it take to fully charge, and is it safe to leave charging overnight?
Should be safe to leave on charging. Auto charging should disable when fully charged, but we're still developing this feature.

### Can I use any charger, or do I need a special one?
Should use only the provided charge stations or seller approved alternatives (eg. from unitree)

### What happens if the battery gets damaged (dropped, punctured)?
If the battery is visibly damaged, broken or non-functioning, please contact Unitree. A replacement will be necessary.

## Children & Pets

### Is it safe to have this running around small kids?
Completely safe.

### Are there safeguards to prevent sudden, jerky movements?
Yes, there are separate movement algorithms by Openmind and Unitree that handle this. Sudden jerky movements are unlikely unless 2 or more feet are not touching the ground at any given moment.

## Physical Safety

### Are there sharp edges, pinch points, or exposed parts?
No sharp edges or pinch points, but it is strongly recommended to avoid touching the backpack and (especially) the sensors like the lidar after prolonged usage.

### What happens if it bumps into furniture — could it damage walls or itself?
Unlikely unless at high speeds or with great force.

### Can it climb stairs safely without falling?
Not at the moment.

## Reliability & Control

### What if the Wi-Fi drops — does the dog freeze, shut down, or keep moving?
If disconnected from the WiFi, the dog will stay in its last recorded valid state (current position). In this case, you may connect to the dog using your phone through the Unitree App and RC it to within connectivity range.

### Is there an emergency stop button or voice command?
E-Stop exists within the Unitree app that shuts down all motors instantly. Additionally, pressing 'B' on the controller will make it stop motion.

### What’s the backup if the AI misunderstands a command?
There is an inbuilt governance model that evaluates commands to make sure they are not misunderstood, the AI is expected to only respond and perform actions within its governance. In case of ambiguity, the AI is expected to query and ask for more information. In case of a violation of its governance, the AI is expected to comply only as far as its governance allows.

## Privacy & Recording

### Is the dog always recording audio/video in my home?
There is an opt-in feature that enables/disables audio and video processing capabilities. Video data is not recorded.

### Where does that data go — cloud or local storage?
Only a live video recording is displayed, it is not stored locally or in the cloud. 

### Can I turn off cameras/mics easily?
You cannot turn off the camera/mic individually, you must turn off the whole system. OM1 will automatically blur faces as a privacy feature. 

## Durability

### How well does it handle drops, spills, or someone tripping over it?
The robot dog can maintain its own balance. Dropping or application of force may damage the electronics or internal components of the dog backpack. It is recommended to avoid any commands that might lead to the robot tilting excessively.

### What’s the expected lifespan of the battery and backpack?
Battery should last 3-4 hours on a single charge, without auto charging

### How weather-proof is it (rain, outdoor use)?
Not waterproof (as of yet) and not intended for inclement weather or rugged outdoor conditions.

## Costs & Maintenance

### How expensive are replacement batteries or repairs if something goes wrong?
Replacement batteries generally cost upwards of $660. In case of any issues with electronics, the robot dog will need to be sent for repairs.

### How often do I need to update software or do maintenance?
OM1 functionality is automatically kept up to date. There is no manual software updates or maintenance required.

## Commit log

2025-09-12 Added main docs and .stl files
    [Base Mount Bracket.stl, Display_Bezel.stl, Dog Backpack BoM v0.2.xlsx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]
2025-09-12 Rename Dog Backpack BoM v0.2.xlsx to Bill of Materials.xlsx
    [Bill of Materials.xlsx, Dog Backpack BoM v0.2.xlsx]
2025-09-12 Update and rename dog-backpack-assembly.md to Assembly.md
2025-09-12 Update and rename Bill of Materials.xlsx to BoM.xlsx
    [BoM.xlsx]
2025-09-17 Added updated CAD models
    [PRISM - Base Mount Bracket.stl, PRISM - Box.stl, PRISM - Lid.stl]
2025-09-19 Updated Head Unit .stl files
    [PRISM - Bezel.stl, PRISM - Head Unit.stl]
2025-09-24 Rename Bill of Materials.md to Bill_of_Materials.md
2025-09-24 Rename PRISM - AGX Push Fit Bracket.stl to PRISM-AGXPushFitBracket.stl
    [PRISM-AGXPushFitBracket.stl]
2025-09-24 Rename PRISM - Bezel.stl to PRISM-Bezel.stl
    [PRISM-Bezel.stl]
2025-09-24 Rename PRISM - Base Mount Bracket.stl to PRISM-BaseMountBracket.stl
    [PRISM-BaseMountBracket.stl]
2025-09-24 Rename PRISM - Box.stl to PRISM-Box.stl
    [PRISM-Box.stl]
2025-09-24 Rename PRISM - Lid.stl to PRISM-BoxLid.stl
    [PRISM-BoxLid.stl]
2025-09-24 Rename PRISM - Head Unit.stl to PRISM-FrontHousing.stl
    [PRISM-FrontHousing.stl]
2025-09-25 Rename ComputerMountAGX - Box2.stl to PRISM-Box.stl
    [PRISM-Box.stl]
2026-04-20 start to update
    [BoM.xlsx]
2026-04-26 finish brainpack writeup
    [PRISM-AGXPushFitBracket.stl, PRISM-BaseMountBracket.stl, PRISM-Bezel.stl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]
2026-04-26 add all stls
    [CameraEnclosure.stl, CameraLid.stl, FaceBack.stl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]
2026-04-26 update stl
    [FaceBack.stl, FaceBack_G1.stl, Head.stl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]
2026-04-26 reduce file sizes
    [ThorCradle.stl, ThorHoldPlate_Left.stl, ThorHoldPlate_Right.stl]
2026-05-03 update power hub material
2026-05-08 Add cost estimate (#1)
    * added excel sheet eith cost estimate for building a brainpack
    * add note for price approximation
    * Update Materials.md
    ---------
